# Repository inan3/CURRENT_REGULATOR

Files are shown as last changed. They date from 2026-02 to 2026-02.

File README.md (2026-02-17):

PCB Module based on STM32G491RET6 acting as a water sensor just for tests purposes. Nominal working voltage is 12V.
It is designed to receive commands either by UART or LIN-BUS containing info about:
  1. How many voltage between 0-3.3V to put in a connector A. 
     DAC_OUT1 from the STM32 is used for this purpose.
  2. How many current between 0-20mA to put in a connector B.
     DAC_OUT2 from the STM32 is used for this purpose. An equivalent voltage is generated from the DAC that will go through a phase of voltage-current conversion with the Improved Howland Current Pump achieving an outside current from 0mA to 20mA with 0V-3.3V.
  3. Toggle between 0V & 12V that must reach a connector C.
     This phase is achieved with high side switching topology to toggle 4 different pins of 2 separate connectores to toggle between 0V and 12V.

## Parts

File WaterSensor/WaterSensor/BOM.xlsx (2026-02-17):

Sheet: BOM
Reference | Manufacturer P/N | JLCPCB P/N | Value | Manufacturer
C1 | CC0603JRX7R9BB104 | C91183 | 100nF 50V X7R ±5% 0603 | YAGEO
C2, C3 | CC0603CRNPO9BN8R2 | C277519 | 50V 8.2pF NP0 0603 | YAGEO
C4 | CC0603JRX7R9BB224 | C519575 | 220nF 50V X7R ±5% 0603 | YAGEO
C5, C6, C7 | CC0603KRX5R5BB106 | C109455 | 10uF 6.3V X5R ±10% | YAGEO
C8, C18 | CC0603JRX7R9BB103 | C115056 | 10nF 50V X7R ±5% 0603 | YAGEO
C9, C17, C20 | CC0603KRX5R9BB105 | C128624 | 1uF 50V X5R ±10% 0603 | YAGEO
C10, C11, C12, C13, C14, C16, C19, C35 | CC0603JRX7R9BB104 | C91183 | 100nF 50V X7R ±5% 0603 | YAGEO
C15 | CC0603KRX5R8BB475 | C326580 | 25V 4.7uF X5R ±10% 0603 | YAGEO
C21 | CC0603JRNPO9BN102 | C106246 | 1nF 50V NP0 ±5% 0603 | YAGEO
C22, C23 | CC0603KRX5R8BB225 | C309478 | 2.2uF 25V X5R ±10% 0603 | YAGEO
C24, C25, C26, C27, C28, C29, C30, C31, C32, C33 | CC0603JRX7R9BB104 | C91183 | 100nF 50V X7R ±5% 0603 | YAGEO
C34 | CC0805KKX5R7BB106 | C89827 | 10uF 16V X5R ±10% 0805 Multilayer Ceramic Capacitors MLCC - SMD/SMT ROHS | YAGEO
D1 | 1N5819WS | C191023 | 1 Independent 1A 25A 40V 500uA@40V 600mV@1A SOD-323 Schottky Diodes ROHS | Guangdong Hottech
D2 | 1N5819WS | C191023 | 1 Independent 1A 25A 40V 500uA@40V 600mV@1A SOD-323 Schottky Diodes ROHS | Guangdong Hottech
D3 | 1N5819WS | C191023 | 1 Independent 1A 25A 40V 500uA@40V 600mV@1A SOD-323 Schottky Diodes ROHS | Guangdong Hottech
D4 | 1N5819WS | C191023 | 1 Independent 1A 25A 40V 500uA@40V 600mV@1A SOD-323 Schottky Diodes ROHS | Guangdong Hottech
D5 | XL-1608UYC-06 | C965802 | Yellow LED | XingLight
D6 | XL-1608UGC-04 | C965804 | Green LED | XingLight
D7 | XL-1608SURC-06 | C965799 | Red LED | XingLight
D8 | XL-1608UBC-04 | C965807 | Blue LED | XingLight
FB1, FB3 | BLM18EG101TN1D | C76893 | -55℃~+125℃ 1 100Ω@100MHz 2A 45mΩ ±25% 0603 Ferrite Beads ROHS | Murata Electronics
FB2 | BLM18AG601SH1D | C73225 | -55℃~+125℃ 1 380mΩ 500mA 600Ω@100MHz ±25% 0603 Ferrite Beads ROHS | Murata Electronics
J1 | 20021321-00014C1LF | C3319516 | -40℃~+105℃ 1.27mm 1.27mm 14P 2 4.5mm Phosphor bronze Square Hole Surface Mount,Vertical Tin SMD,P=1.27mm Female Headers ROHS | Amphenol ICC
J2, J3, J7, J8 | 1724480002 | C5188718 | -40℃~+105℃ 1 13A 2 2P 2x1P 4.2mm 4.2mm 600V Black Brass PA Right Angle Tin UL94V-2 Plugin Wire To Board Connector ROHS | Molex
J4 | 436500427 | C563850 | -40℃~+105℃ 1 18.65mm 1x5P 3mm 5 5.57mm 5P 600V 8.5A 9.9mm Black Brass Micro-Fit(MX 3.0) Pillar Through Hole Tin UL94V-0 Plugin,P=3mm Wire To Board Connector ROHS | Molex
J5 | 436500527 | C19183988 | -40℃~+105℃ 1 15.65mm 1x4P 3mm 4 4P 600V 8.5A Black Brass Through Hole Tin UL94V-0 Plugin,P=3mm Wire To Board Connector ROHS | Molex
J6 | 65100516121 | C5120592 | -40℃~+105℃ 1 1A 30V 5P Black Female Mini-B Surface Mount, Right Angle USB 2.0 SMD USB Connectors ROHS | Würth Elektronik
Q1, Q2, Q3, Q4, Q5, Q6, Q7, Q8 | BC848BLT1G | C163725 | -55℃~+150℃ 1 NPN 100MHz 100mA 110 225mW 250mV 30V 5V 5uA NPN SOT-23 Bipolar (BJT) ROHS | Onsemi
QM1, QM2, QM3, QM4, QM5, QM6, QM7, QM8 | SIS427EDN-T1-GE3 | C727478 | -55℃~+150℃ 1 P-Channel 1.2V 1.93nF 10.6mΩ@10V 15A 3.7W、52W 30V 66nC@10V PowerPAK1212-8 MOSFETs ROHS | Vishay Intertech
R1, R2, R3, R4, R5, R6, R7, R8 | CRT0603-BY-1003ELF | C4332041 | -55℃~+155℃ 100kΩ 100mW Thin Film Resistor ±0.1% ±25ppm/℃ 0603 Chip Resistor - Surface Mount ROHS | Bourns Inc.
R9, R10, R11 | RS-03K1001FT | C115325 | -55℃~+155℃ 100mW 1kΩ 50V Thick Film Resistor ±1% ±100ppm/℃ 0603 Chip Resistor - Surface Mount ROHS | FH (Guangdong Fenghua Advanced Tech)
R12 | RT0603BRE0750RL | C849792 | RES SMD 50 OHM 0.1% 1/10W 0603 | YAGEO
R13, R14, R15, R16 | EXB-28V220JX | C2649457 | 22Ω 4 63mW 8 ±200ppm/℃ ±5% 0402x4 Resistor Networks, Arrays ROHS | Panasonic Electronic Components
R17, R18, R19 | CR0603-FX-22R0ELF | C203424 | RES SMD 22 OHM 1% 1/10W 0603 | Bourns Inc.
R20 | CR0603-FX-1000ELF | C203215 | RES SMD 100 OHM 1% 1/10W 0603 | Bourns Inc.
R21, R22 | CR0603-FX-2200ELF | C203410 | RES SMD 220 OHM 1% 1/10W 0603 | Bourns Inc.
R23, R24 | CR0603-FX-1200ELF | C203262 | RES SMD 120 OHM 1% 1/10W 0603 | Bourns Inc.
R25, R26 | CR0603-FX-1002ELF | C840630 | RES SMD 10K OHM 1% 1/10W 0603 | Bourns Inc.
R27 | CRCW06031K50FKEAC | C844332 | RES 1.5K OHM 1% 1/10W 0603 | Vishay Dale
RSense1, RSense2 | RT0603BRD07165RL | C861151 | -55℃~+155℃ 100mW 165Ω 75V Thin Film Resistor ±0.1% ±25ppm/℃ 0603 Chip Resistor - Surface Mount ROHS | YAGEO
SW1 | TS04-66-43-BK-160-SMT | C4364498 | Switch | Same Sky (Formerly CUI Devices)
U1 | STM32G491RET6 | C3231005 | IC MCU 32BIT 512KB FLASH 64LQFP | STMicroelectronics
U2, U3, U8, U9, U14 | OPA2990IDR | C2058283 | IC OPAMP GP 2 CIRCUIT 8SOIC | Texas Instruments
U4 | LM1117MPX-3.3/NOPB | C9662 | IC REG LIN 3.3V 800MA SOT-223-4 | Texas Instruments
U5 | LM7805MPX/NOPB | C2848241 | IC REG LINEAR 5V 1.5A SOT-223-4 | Texas Instruments
U6 | TS5A23157QDGSRQ1 | C523778 | IC SWITCH SPDT X 2 15OHM 10VSSOP | Texas Instruments
U7 | TPD2E001DRLR | C150526 | TVS DIODE 5.5VWM SOT5 | Texas Instruments
U10 | CH340E | C99652 | USB/UART
U11 | MCP1501T-33E/CHY | C2156758 | IC VREF SERIES 3.3V SOT23-6 | Microchip Technology
U12 | TLIN1029DRQ1 | C190544 | Transceptor 1/1 LINbus 8-SOIC | Texas Instruments
U13 | SN74LV4051APWR | C7793 | IC MUX 8:1 75OHM 16TSSOP | Texas Instruments
U15 | OPA990IDBVR | C1855809 | -20V~-1.35V、1.35V~20V -40℃~+125℃ 1 1.1MHz 10pA 115dB 120uA 2.7V~40V 300uV 30nV/√Hz@1kHz 4.5V/us 40V 5pA 600nV/℃ 80mA Rail-to-Rail Input, Rail-to-Rail Output SOT-23-5 Operational Amplifier ROHS | Texas Instruments
XTAL1 | FA-128 24.0000MB-W | C2449805 | CRYSTAL 24.0000MHZ 12PF SMD | ECS

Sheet: Test
DigiKey P/N | Cantidad
OPA2990IDR | 5 | OPA2990IDR Texas Instruments | Integrated Circuits (ICs) | DigiKey (https://www.digikey.es/en/products/detail/texas-instruments/OPA2990IDR/10270185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) |  | ok
SN74LV4051APWR | 3 | SN74LV4051APWR Texas Instruments | Integrated Circuits (ICs) | DigiKey (https://www.digikey.es/en/products/detail/texas-instruments/SN74LV4051APWR/374749) |  | ok
BC848BLT1G | 5 | BC848BLT1G onsemi | Discrete Semiconductor Products | DigiKey (https://www.digikey.es/en/products/detail/onsemi/BC848BLT1G/918348) |  | ok
SIS427EDN-T1-GE3 | 5 | SIS427EDN-T1-GE3 Vishay Siliconix | Discrete Semiconductor Products | DigiKey (https://www.digikey.es/en/products/detail/vishay-siliconix/SIS427EDN-T1-GE3/4327726) |  | ok
TS5A23157QDGSRQ1 | 2 | TS5A23157QDGSRQ1 Texas Instruments | Integrated Circuits (ICs) | DigiKey (https://www.digikey.es/en/products/detail/texas-instruments/TS5A23157QDGSRQ1/3996775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) |  | ok
C321C103K3G5TA | 8 |  | 10nF | ok
K104K15X7RF5TL2 | 15 |  | 100nF | ok
MFP-25BRD52-100K | 16 |  | 100k | ok
MFR-25FRF52-165R | 8 |  | 165 | ok

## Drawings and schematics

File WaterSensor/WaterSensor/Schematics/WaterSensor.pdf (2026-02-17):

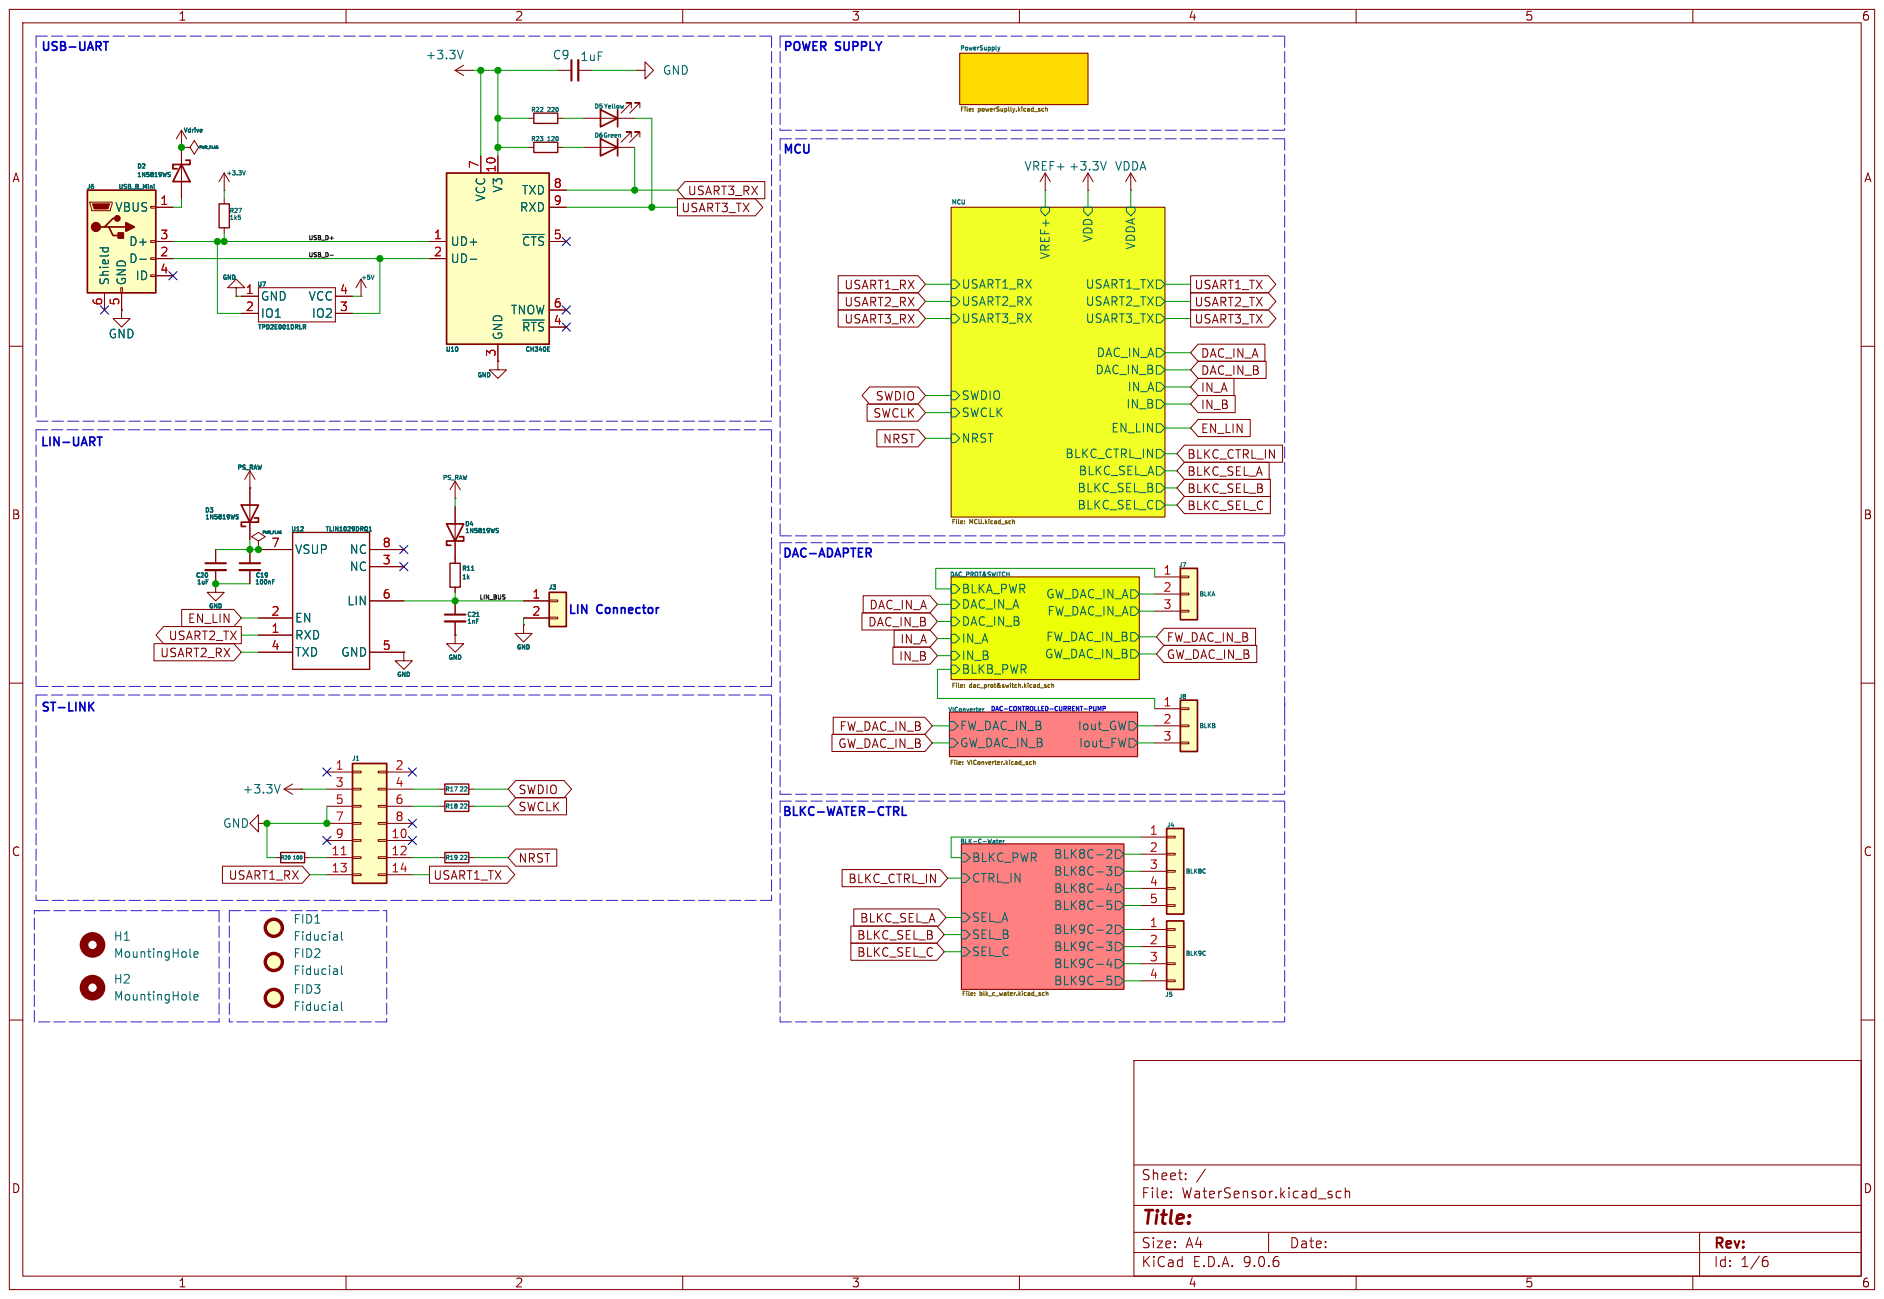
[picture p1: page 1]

Id: 1/6 Title: File: WaterSensor.kicad_sch Sheet: /

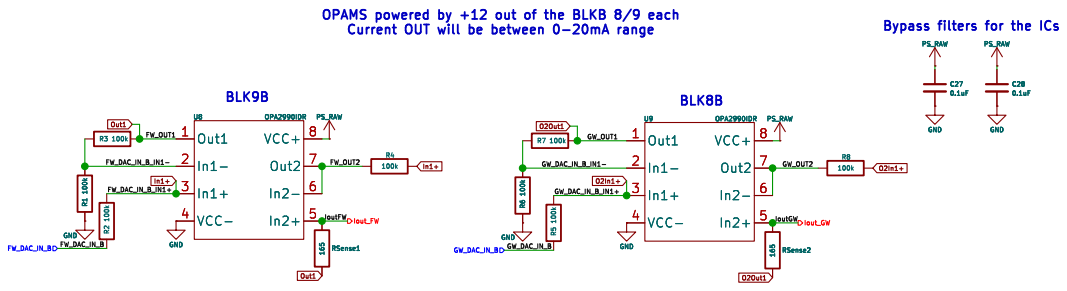
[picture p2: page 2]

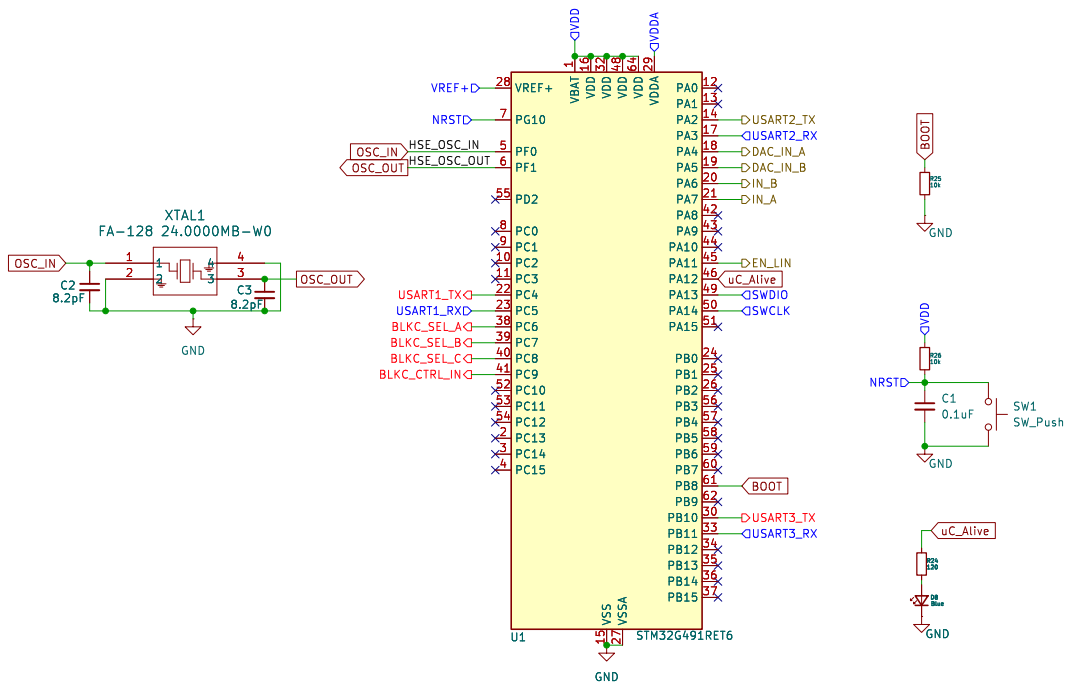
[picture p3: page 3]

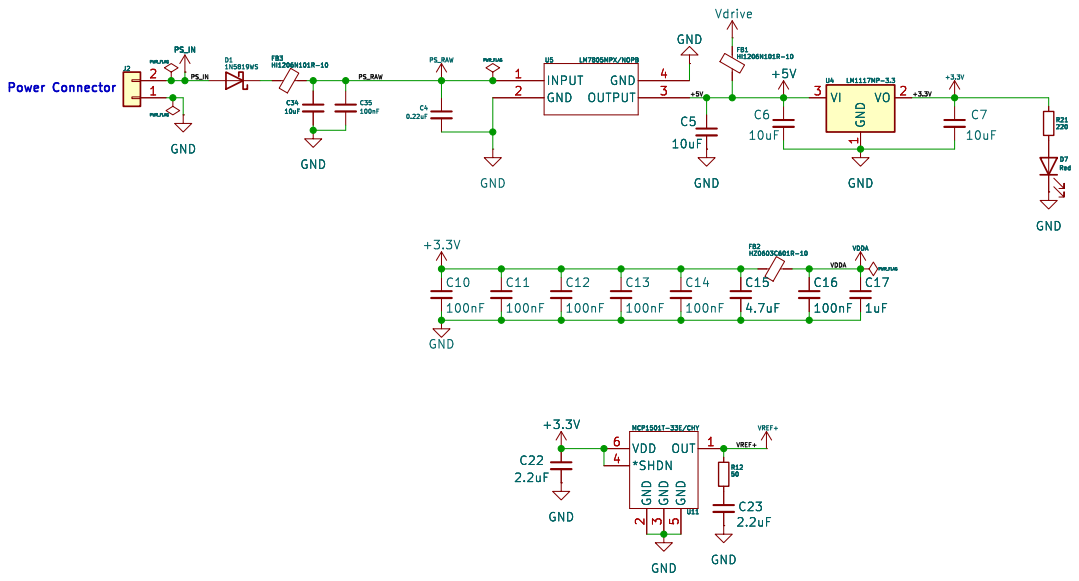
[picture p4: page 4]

Id: 4/6 Title: File: powerSuplly.kicad_sch Sheet: /PowerSupply/

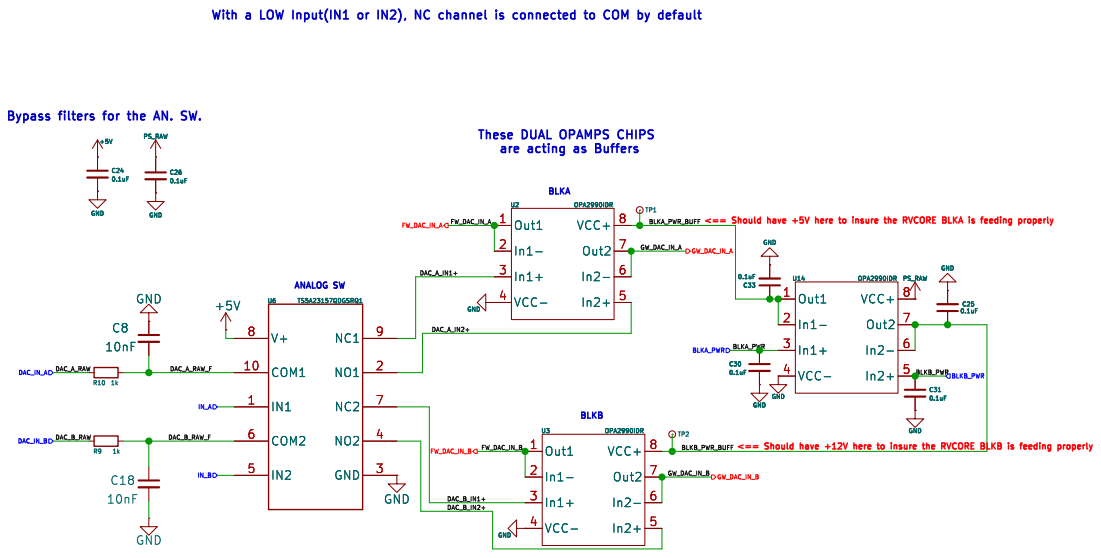
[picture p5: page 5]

Id: 5/6 Title: File: dac_prot&switch.kicad_sch Sheet: /DAC_PROT&SWITCH/

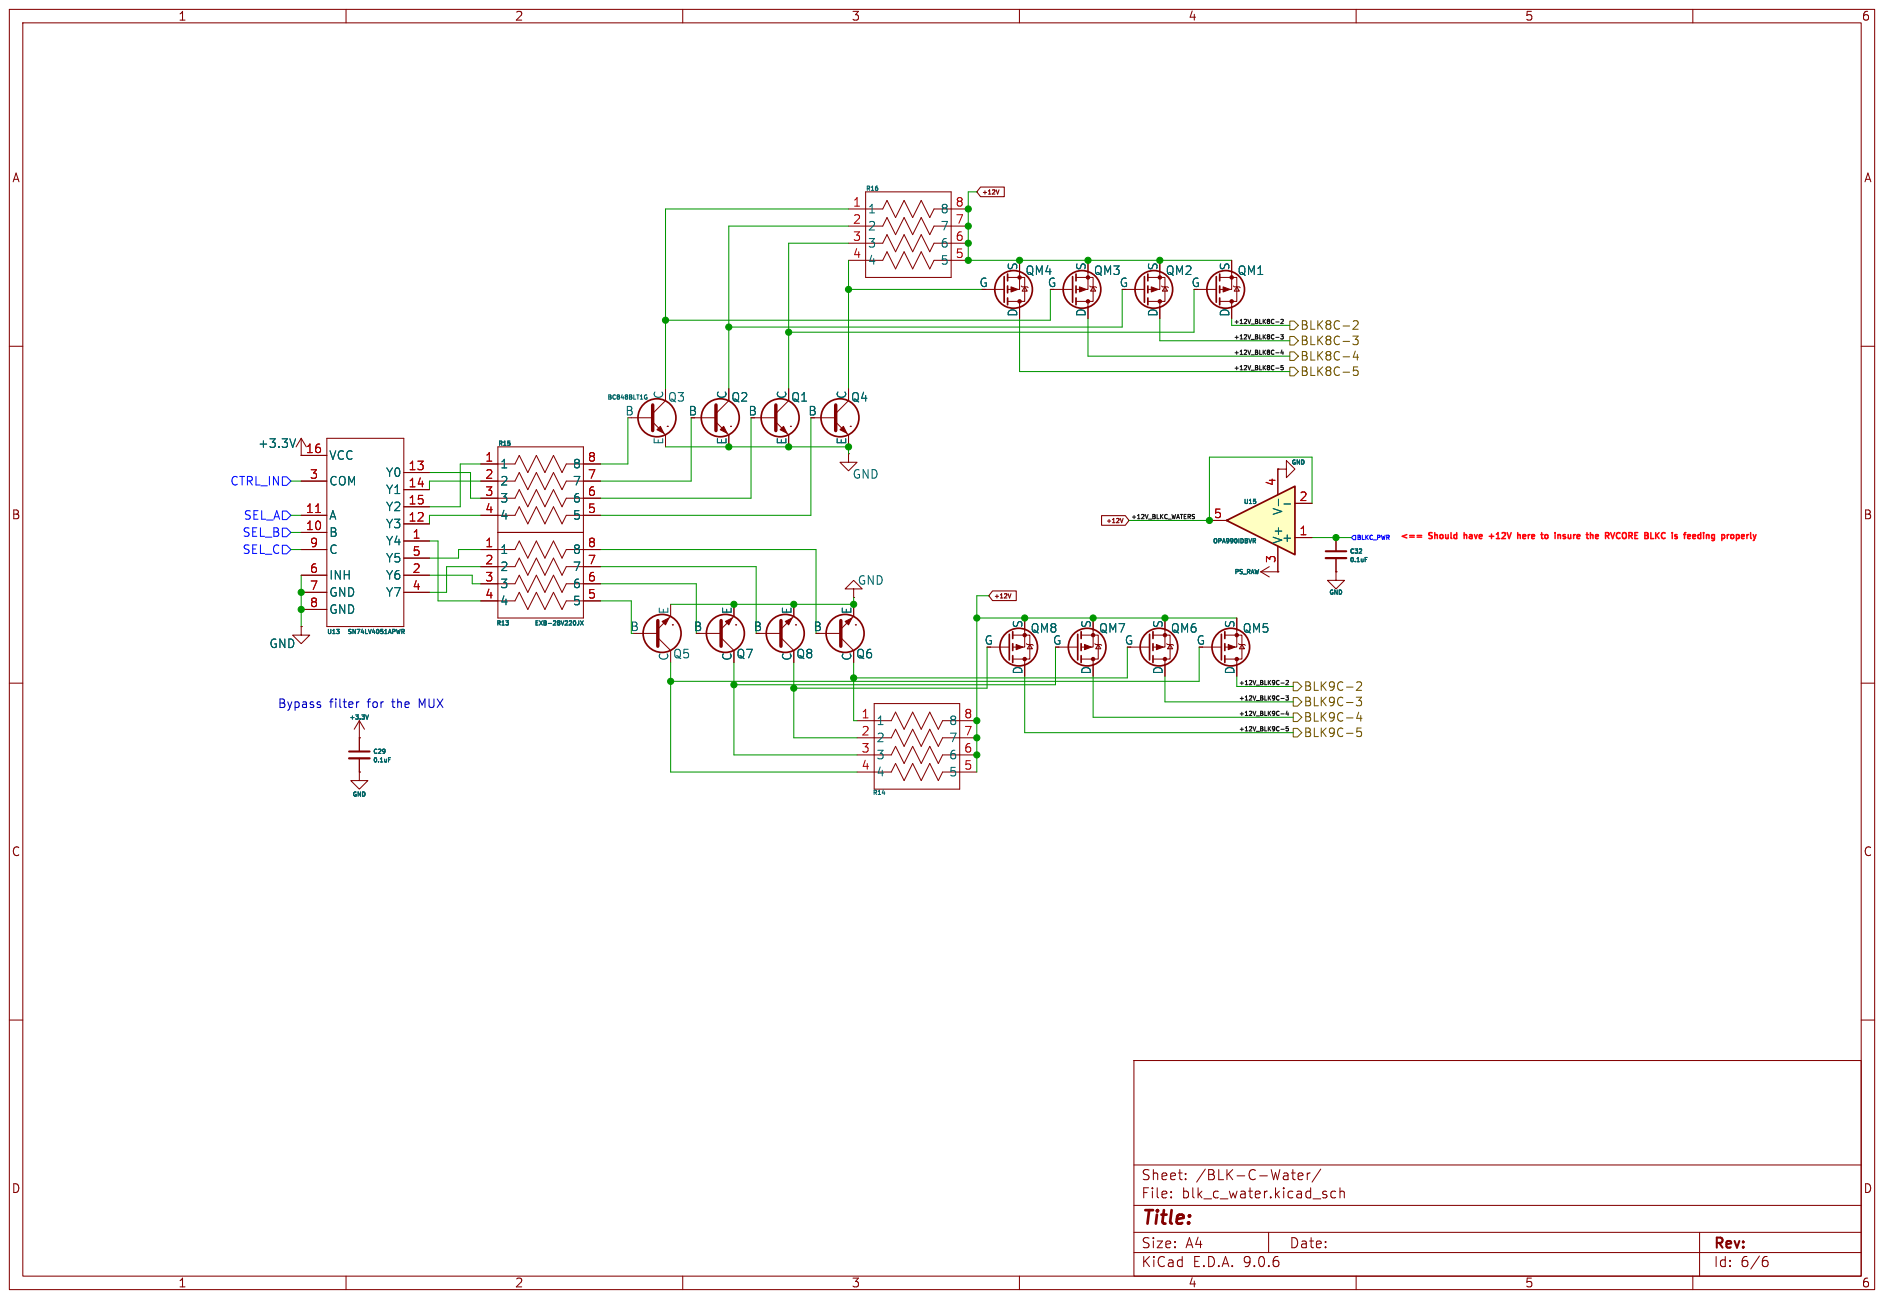
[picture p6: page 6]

+12V_BLK8C-2 +12V_BLK8C-4 +12V_BLK8C-5 Bypass filter for the MUX

Id: 6/6 Title: File: blk_c_water.kicad_sch Sheet: /BLK-C-Water/

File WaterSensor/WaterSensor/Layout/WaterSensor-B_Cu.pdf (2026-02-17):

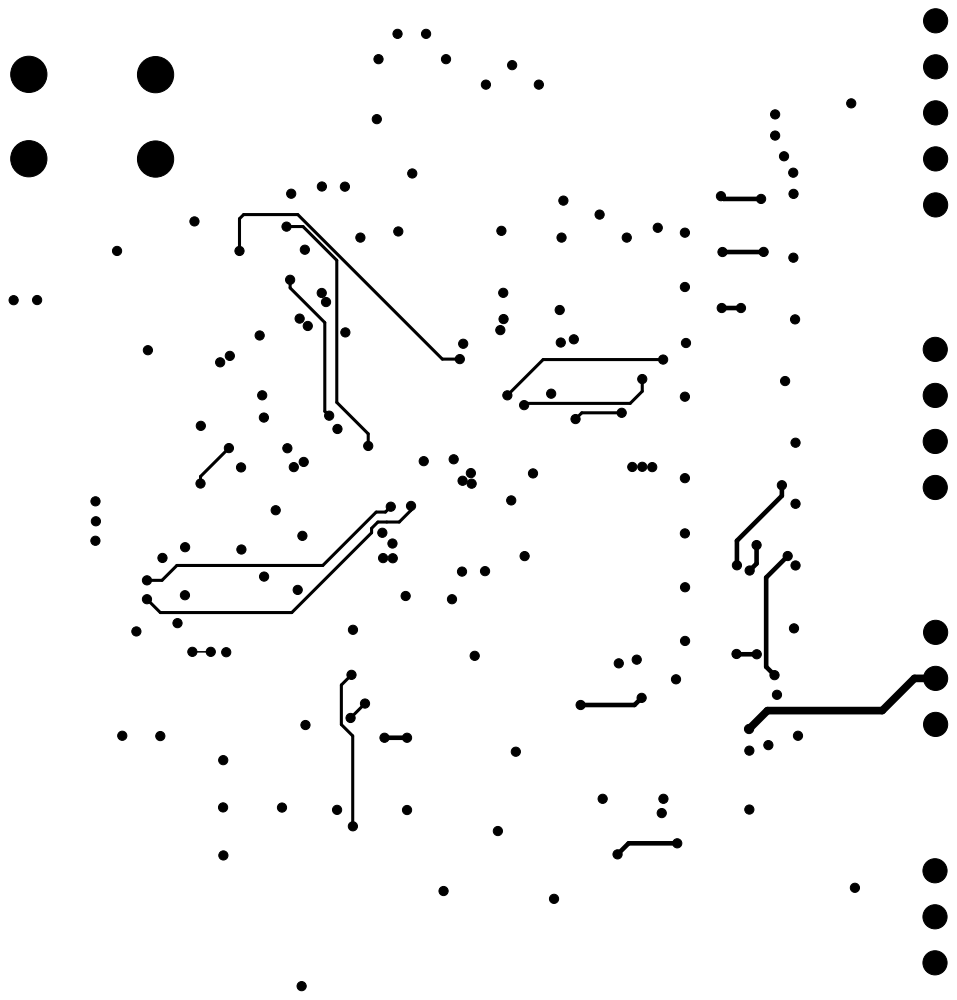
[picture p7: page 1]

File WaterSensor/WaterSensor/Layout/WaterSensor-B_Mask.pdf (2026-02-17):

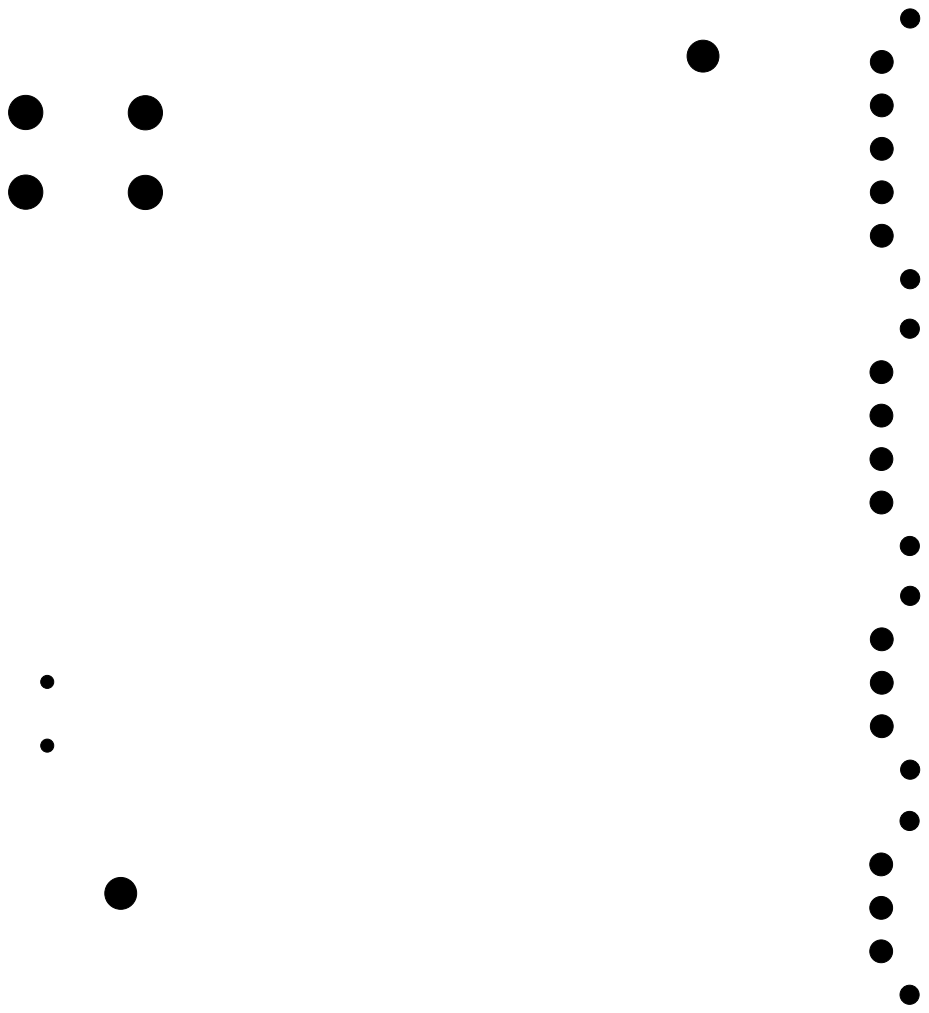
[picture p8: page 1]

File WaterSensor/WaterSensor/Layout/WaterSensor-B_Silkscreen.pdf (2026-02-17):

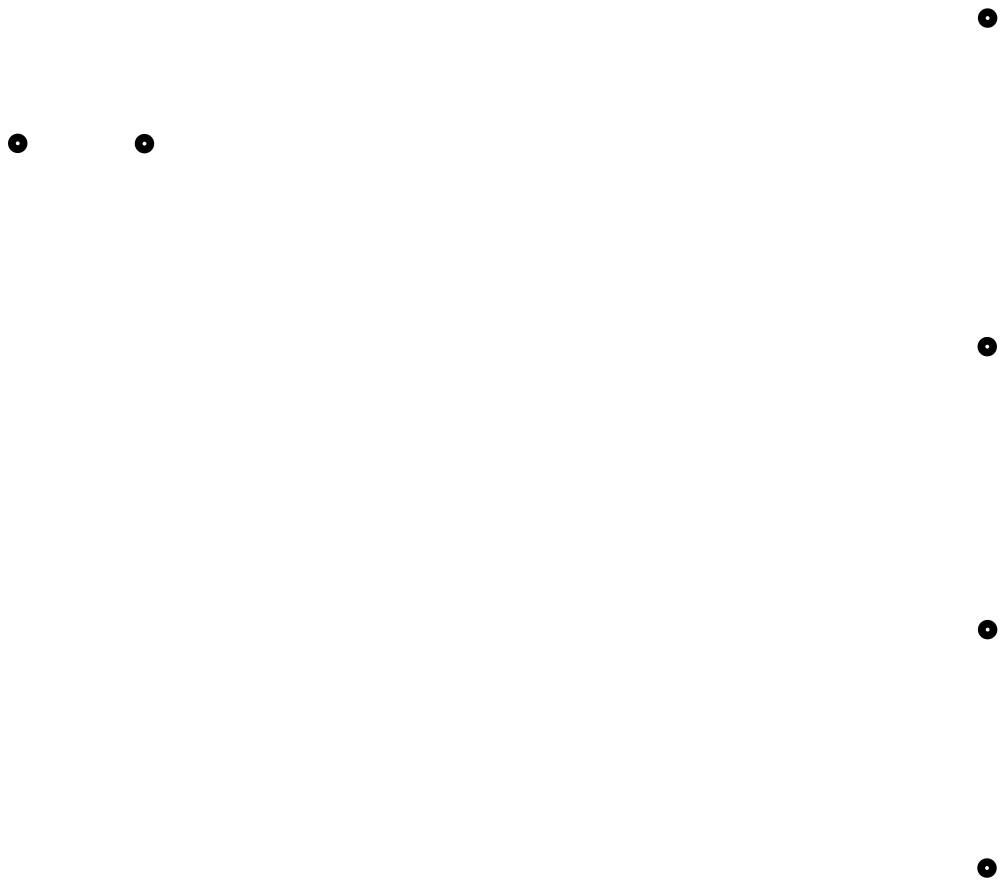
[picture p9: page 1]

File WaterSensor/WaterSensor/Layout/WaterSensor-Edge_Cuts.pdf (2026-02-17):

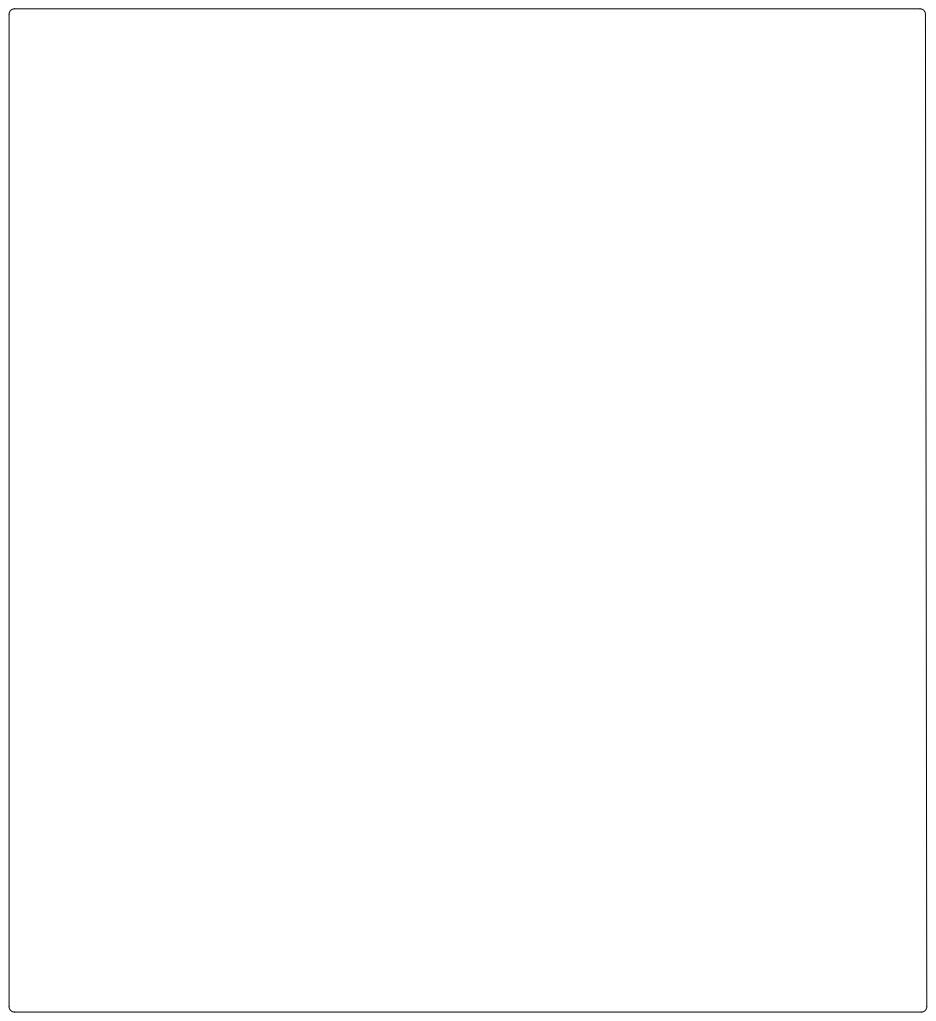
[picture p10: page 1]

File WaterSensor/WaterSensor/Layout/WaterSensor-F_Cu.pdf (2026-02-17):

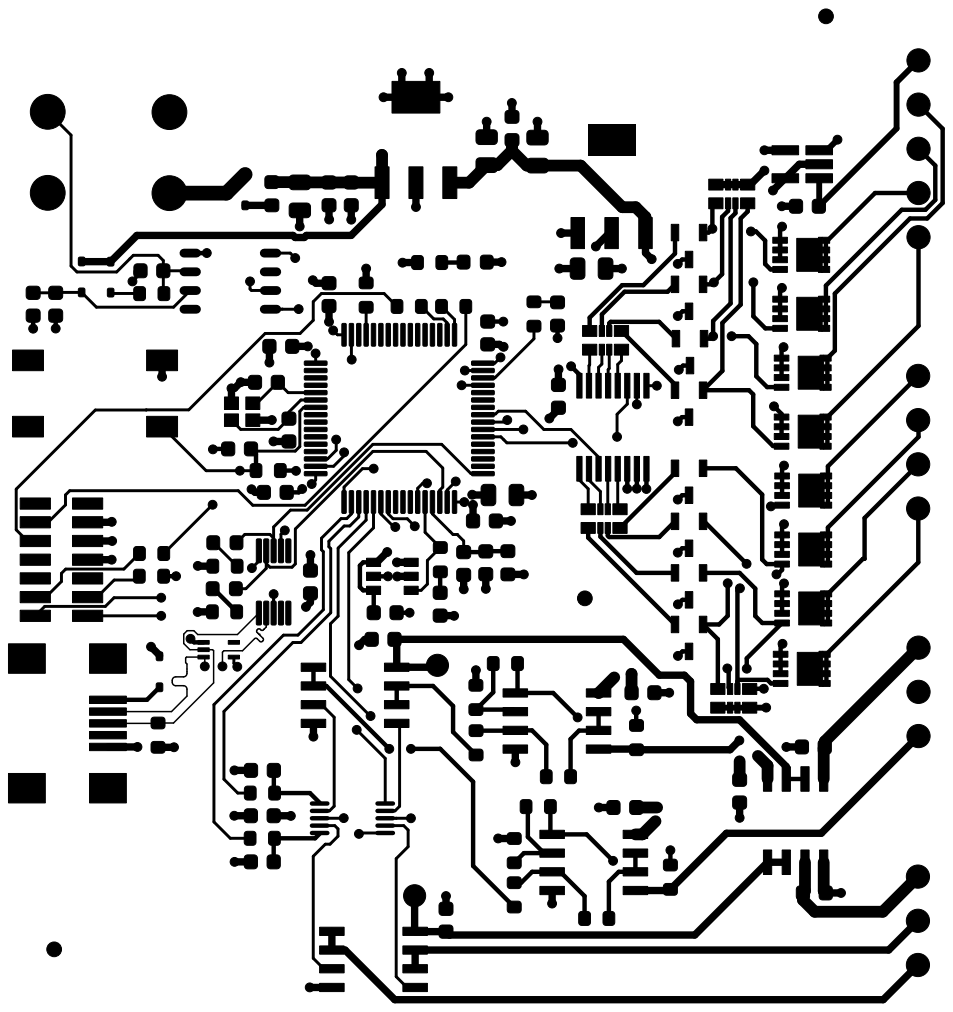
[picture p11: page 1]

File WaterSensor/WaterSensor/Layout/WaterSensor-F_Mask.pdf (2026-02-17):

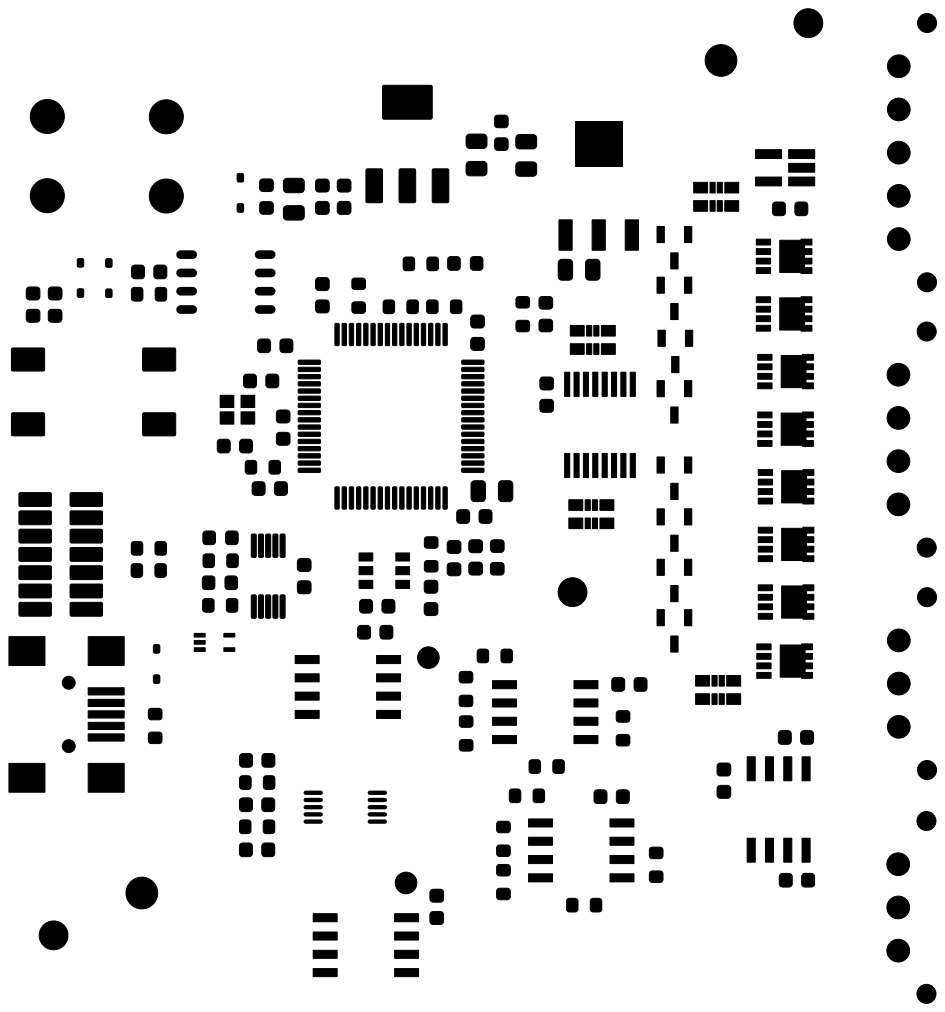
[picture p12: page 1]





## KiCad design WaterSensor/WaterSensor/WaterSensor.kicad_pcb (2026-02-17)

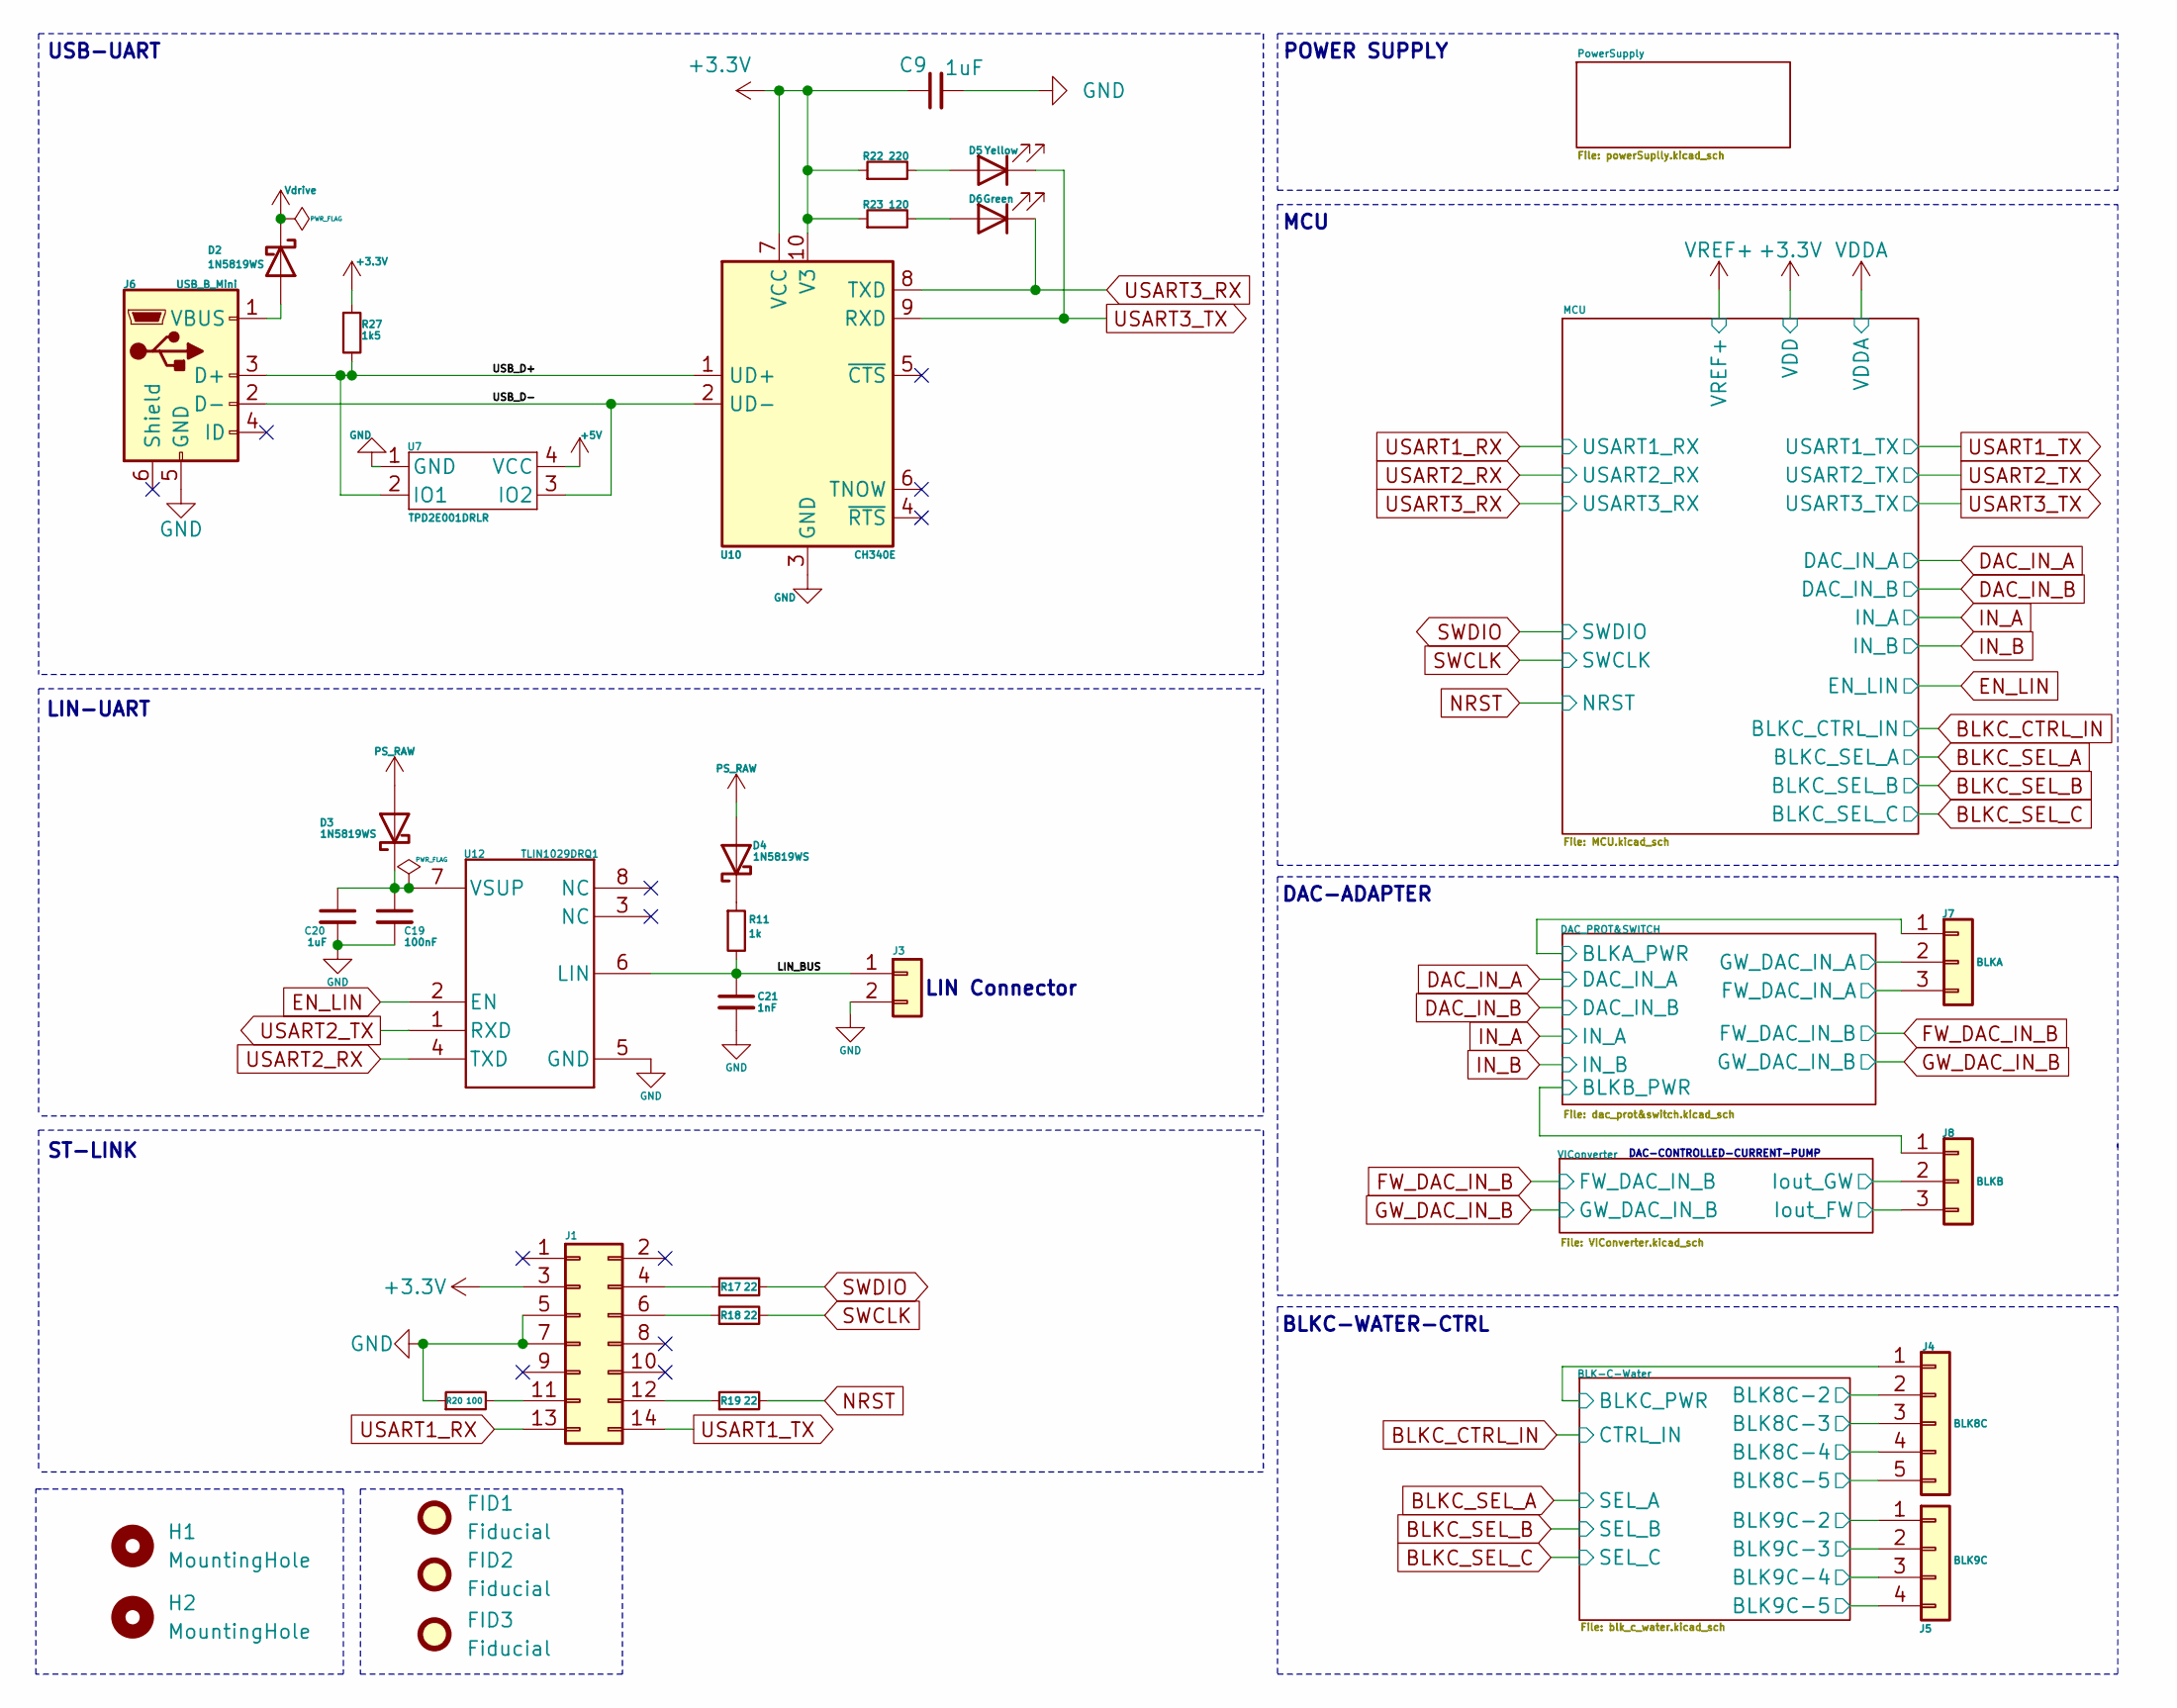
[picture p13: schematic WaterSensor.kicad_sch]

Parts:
C9, C20: 1uF; C_0603_1608Metric
C19: 100nF; C_0603_1608Metric
C21: 1nF; C_0603_1608Metric
D2, D3, D4: 1N5819WS; D_SOD-323
D5: Yellow; LED_0603_1608Metric
D6: Green; LED_0603_1608Metric
FID1, FID2, FID3: Fiducial; Fiducial_1mm_Mask2mm
H1, H2: MountingHole; MountingHole_2.2mm_M2
J1: ST-LINK; Connector_IDC_02x07_1_27mm_SMD
J3: LIN; Conn_1x2_MiniFit_1724480002
J4: BLK8C; Conn_1x5_MicroFit_436500527
J5: BLK9C; Conn_1x4_MicroFit_0436500427
J6: USB_B_Mini; USB_Mini-B_Wuerth_65100516121_Horizontal
J7: BLKA; Conn_1x3_MicroFit_436500327
J8: BLKB; Conn_1x3_MicroFit_436500327
R11: 1k; R_0603_1608Metric
R17, R18, R19: 22; R_0603_1608Metric
R20: 100; R_0603_1608Metric
R22: 220; R_0603_1608Metric
R23: 120; R_0603_1608Metric
R27: 1k5; R_0603_1608Metric
U7: TPD2E001DRLR; DRL5-M
U10: CH340E; MSOP-10_3x3mm_P0.5mm
U12: TLIN1029DRQ1; D0008A_N

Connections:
+3.3V: C9.1, J1.3, R22.1, R23.1, R27.1, U10.7 (VCC), U10.10 (V3); also elsewhere on the board
+5V: U7.4 (VCC); also elsewhere on the board
/BLK-C-Water/+12V_BLK8C-2: J4.2; also elsewhere on the board
/BLK-C-Water/+12V_BLK8C-3: J4.3; also elsewhere on the board
/BLK-C-Water/+12V_BLK8C-4: J4.4; also elsewhere on the board
/BLK-C-Water/+12V_BLK8C-5: J4.5; also elsewhere on the board
/BLK-C-Water/+12V_BLK9C-2: J5.1; also elsewhere on the board
/BLK-C-Water/+12V_BLK9C-3: J5.2; also elsewhere on the board
/BLK-C-Water/+12V_BLK9C-4: J5.3; also elsewhere on the board
/BLK-C-Water/+12V_BLK9C-5: J5.4; also elsewhere on the board
/BLK-C-Water/BLKC_PWR: J4.1; also elsewhere on the board
/DAC_PROT&SWITCH/BLKA_PWR: J7.1; also elsewhere on the board
/DAC_PROT&SWITCH/BLKB_PWR: J8.1; also elsewhere on the board
/DAC_PROT&SWITCH/FW_DAC_IN_A: J7.3; also elsewhere on the board
/DAC_PROT&SWITCH/GW_DAC_IN_A: J7.2; also elsewhere on the board
/LIN_BUS: C21.1, J3.1, R11.2, U12.6 (LIN)
/USB_D+: J6.3 (D+), R27.2, U7.2 (IO1), U10.1 (UD+)
/USB_D-: J6.2 (D-), U7.3 (IO2), U10.2 (UD-)
/VIConverter/IoutFW: J8.3; also elsewhere on the board
/VIConverter/IoutGW: J8.2; also elsewhere on the board
EN_LIN: U12.2 (EN); also elsewhere on the board
GND: C9.2, C19.2, C20.2, C21.2, J1.5, J1.7, J3.2, J6.5 (GND), R20.1, U7.1 (GND), U10.3 (GND), U12.5 (GND); also elsewhere on the board
NRST: R19.2; also elsewhere on the board
unnamed: D2.2 (A), J6.1 (VBUS)
unnamed: C19.1, C20.1, D3.1 (K), U12.7 (VSUP)
unnamed: D4.1 (K), R11.1
unnamed: D5.2 (A), R22.2
unnamed: D6.2 (A), R23.2
unnamed: J1.4, R17.1
unnamed: J1.6, R18.1
unnamed: J1.11, R20.2
unnamed: J1.12, R19.1
PS_RAW: D3.2 (A), D4.2 (A); also elsewhere on the board
SWCLK: R18.2; also elsewhere on the board
SWDIO: R17.2; also elsewhere on the board
USART1_RX: J1.13; also elsewhere on the board
USART1_TX: J1.14; also elsewhere on the board
USART2_RX: U12.4 (TXD); also elsewhere on the board
USART2_TX: U12.1 (RXD); also elsewhere on the board
USART3_RX: D6.1 (K), U10.8 (TXD); also elsewhere on the board
USART3_TX: D5.1 (K), U10.9 (RXD); also elsewhere on the board
Vdrive: D2.1 (K); also elsewhere on the board

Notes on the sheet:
LIN Connector
DAC-CONTROLLED-CURRENT-PUMP
DAC-ADAPTER
ST-LINK
MCU
LIN-UART
POWER SUPPLY
BLKC-WATER-CTRL
USB-UART

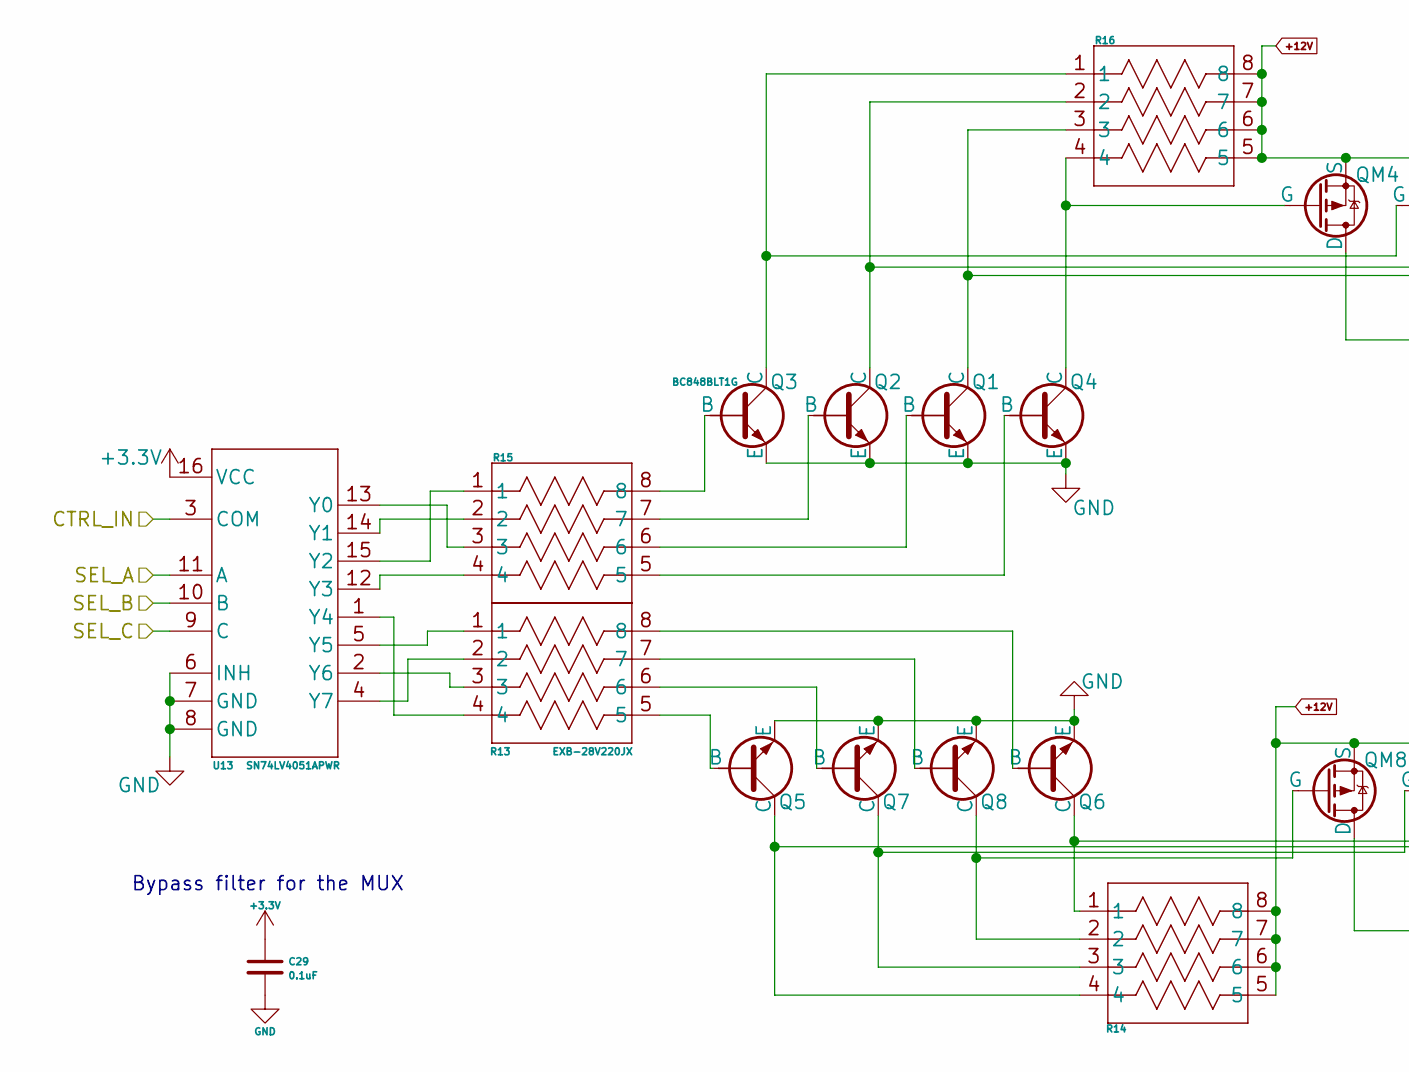
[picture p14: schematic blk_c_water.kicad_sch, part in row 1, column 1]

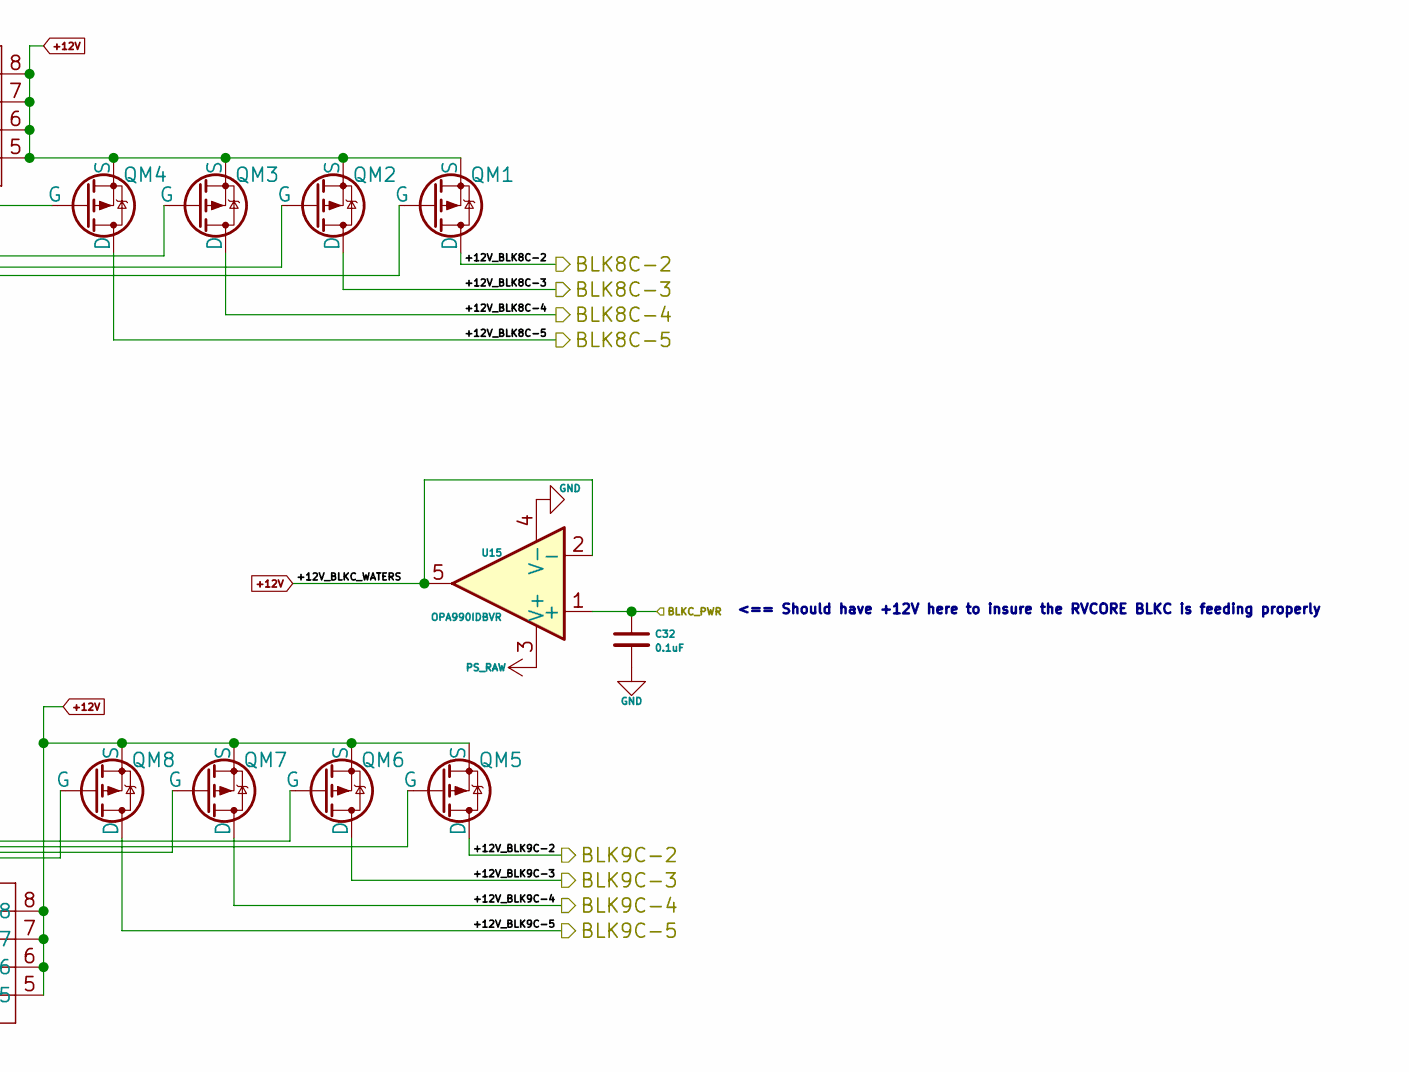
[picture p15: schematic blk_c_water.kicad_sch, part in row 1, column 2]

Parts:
C29, C32: 0.1uF; C_0603_1608Metric
Q1, Q2, Q3, Q4, Q5, Q6, Q7, Q8: BC848BLT1G; SOT-23_ONS-L
QM1, QM2, QM3, QM4, QM5, QM6, QM7, QM8: PMOS; LIB-SIS862DNT1GE3
R13, R14, R15, R16: EXB-28V220JX; EXB28V_PAN
U13: SN74LV4051APWR; PW16
U15: OPA990IDBVR; DBV0005A-IPC_A

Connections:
+3.3V: C29.1, U13.16 (VCC); also elsewhere on the board
+12V: QM1.3 (S), QM2.3 (S), QM3.3 (S), QM4.3 (S), QM5.3 (S), QM6.3 (S), QM7.3 (S), QM8.3 (S), R14.5, R14.6, R14.7, R14.8, R16.5, R16.6, R16.7, R16.8, U15.2 (-), U15.5
/BLK-C-Water/+12V_BLK8C-2: QM1.1 (D); also elsewhere on the board
/BLK-C-Water/+12V_BLK8C-3: QM2.1 (D); also elsewhere on the board
/BLK-C-Water/+12V_BLK8C-4: QM3.1 (D); also elsewhere on the board
/BLK-C-Water/+12V_BLK8C-5: QM4.1 (D); also elsewhere on the board
/BLK-C-Water/+12V_BLK9C-2: QM5.1 (D); also elsewhere on the board
/BLK-C-Water/+12V_BLK9C-3: QM6.1 (D); also elsewhere on the board
/BLK-C-Water/+12V_BLK9C-4: QM7.1 (D); also elsewhere on the board
/BLK-C-Water/+12V_BLK9C-5: QM8.1 (D); also elsewhere on the board
/BLK-C-Water/BLKC_PWR: C32.1, U15.1 (+); also elsewhere on the board
BLKC_CTRL_IN: U13.3 (COM); also elsewhere on the board
BLKC_SEL_A: U13.11 (A); also elsewhere on the board
BLKC_SEL_B: U13.10 (B); also elsewhere on the board
BLKC_SEL_C: U13.9 (C); also elsewhere on the board
GND: C29.2, C32.2, Q1.3 (E), Q2.3 (E), Q3.3 (E), Q4.3 (E), Q5.3 (E), Q6.3 (E), Q7.3 (E), Q8.3 (E), U13.6 (INH), U13.7 (GND), U13.8 (GND), U15.4 (V-); also elsewhere on the board
unnamed: Q1.2 (B), R15.6
unnamed: Q1.1 (C), QM1.2 (G), R16.3
unnamed: Q2.2 (B), R15.7
unnamed: Q2.1 (C), QM2.2 (G), R16.2
unnamed: Q3.2 (B), R15.8
unnamed: Q3.1 (C), QM3.2 (G), R16.1
unnamed: Q4.2 (B), R15.5
unnamed: Q4.1 (C), QM4.2 (G), R16.4
unnamed: Q5.2 (B), R13.5
unnamed: Q5.1 (C), QM5.2 (G), R14.4
unnamed: Q6.2 (B), R13.8
unnamed: Q6.1 (C), QM6.2 (G), R14.1
unnamed: Q7.2 (B), R13.6
unnamed: Q7.1 (C), QM7.2 (G), R14.3
unnamed: Q8.2 (B), R13.7
unnamed: Q8.1 (C), QM8.2 (G), R14.2
unnamed: R15.3, U13.13 (Y0)
unnamed: R15.2, U13.14 (Y1)
unnamed: R15.1, U13.15 (Y2)
unnamed: R15.4, U13.12 (Y3)
unnamed: R13.4, U13.1 (Y4)
unnamed: R13.1, U13.5 (Y5)
unnamed: R13.3, U13.2 (Y6)
unnamed: R13.2, U13.4 (Y7)
PS_RAW: U15.3 (V+); also elsewhere on the board

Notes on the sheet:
<== Should have +12V here to insure the RVCORE BLKC is feeding properly
Bypass filter for the MUX

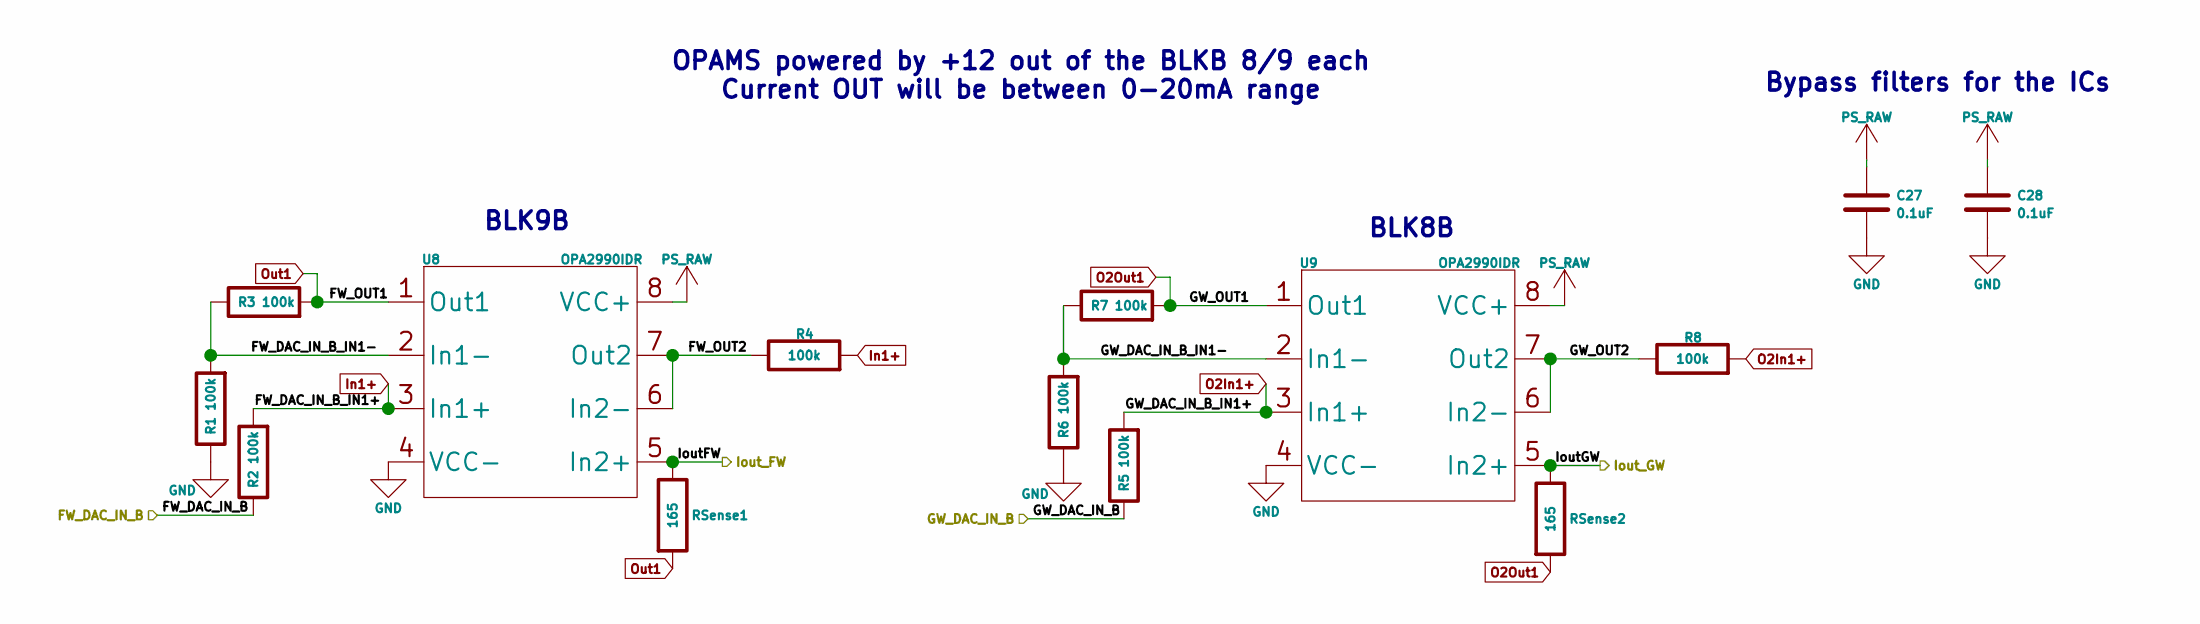
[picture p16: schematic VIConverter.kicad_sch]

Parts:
C27, C28: 0.1uF; C_0603_1608Metric
R1, R2, R3, R4, R5, R6, R7, R8: 100k; R_0603_1608Metric
RSense1, RSense2: 165; R_0603_1608Metric
U8, U9: OPA2990IDR; D8_TEX-M

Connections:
/VIConverter/FW_DAC_IN_B_IN1-: R1.2, R3.1, U8.2 (In1-)
/VIConverter/FW_OUT2: R4.1, U8.6 (In2-), U8.7 (Out2)
/VIConverter/GW_DAC_IN_B_IN1-: R6.2, R7.1, U9.2 (In1-)
/VIConverter/GW_OUT2: R8.1, U9.6 (In2-), U9.7 (Out2)
/VIConverter/IoutFW: RSense1.1, U8.5 (In2+); also elsewhere on the board
/VIConverter/IoutGW: RSense2.1, U9.5 (In2+); also elsewhere on the board
FW_DAC_IN_B: R2.1; also elsewhere on the board
GND: C27.2, C28.2, R1.1, R6.1, U8.4 (VCC-), U9.4 (VCC-); also elsewhere on the board
GW_DAC_IN_B: R5.1; also elsewhere on the board
In1+: R2.2, R4.2, U8.3 (In1+)
O2In1+: R5.2, R8.2, U9.3 (In1+)
O2Out1: R7.2, RSense2.2, U9.1 (Out1)
Out1: R3.2, RSense1.2, U8.1 (Out1)
PS_RAW: C27.1, C28.1, U8.8 (VCC+), U9.8 (VCC+); also elsewhere on the board

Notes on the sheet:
BLK8B
BLK9B
Bypass filters for the ICs
OPAMS powered by +12 out of the BLKB 8/9 each Current OUT will be between 0-20mA range

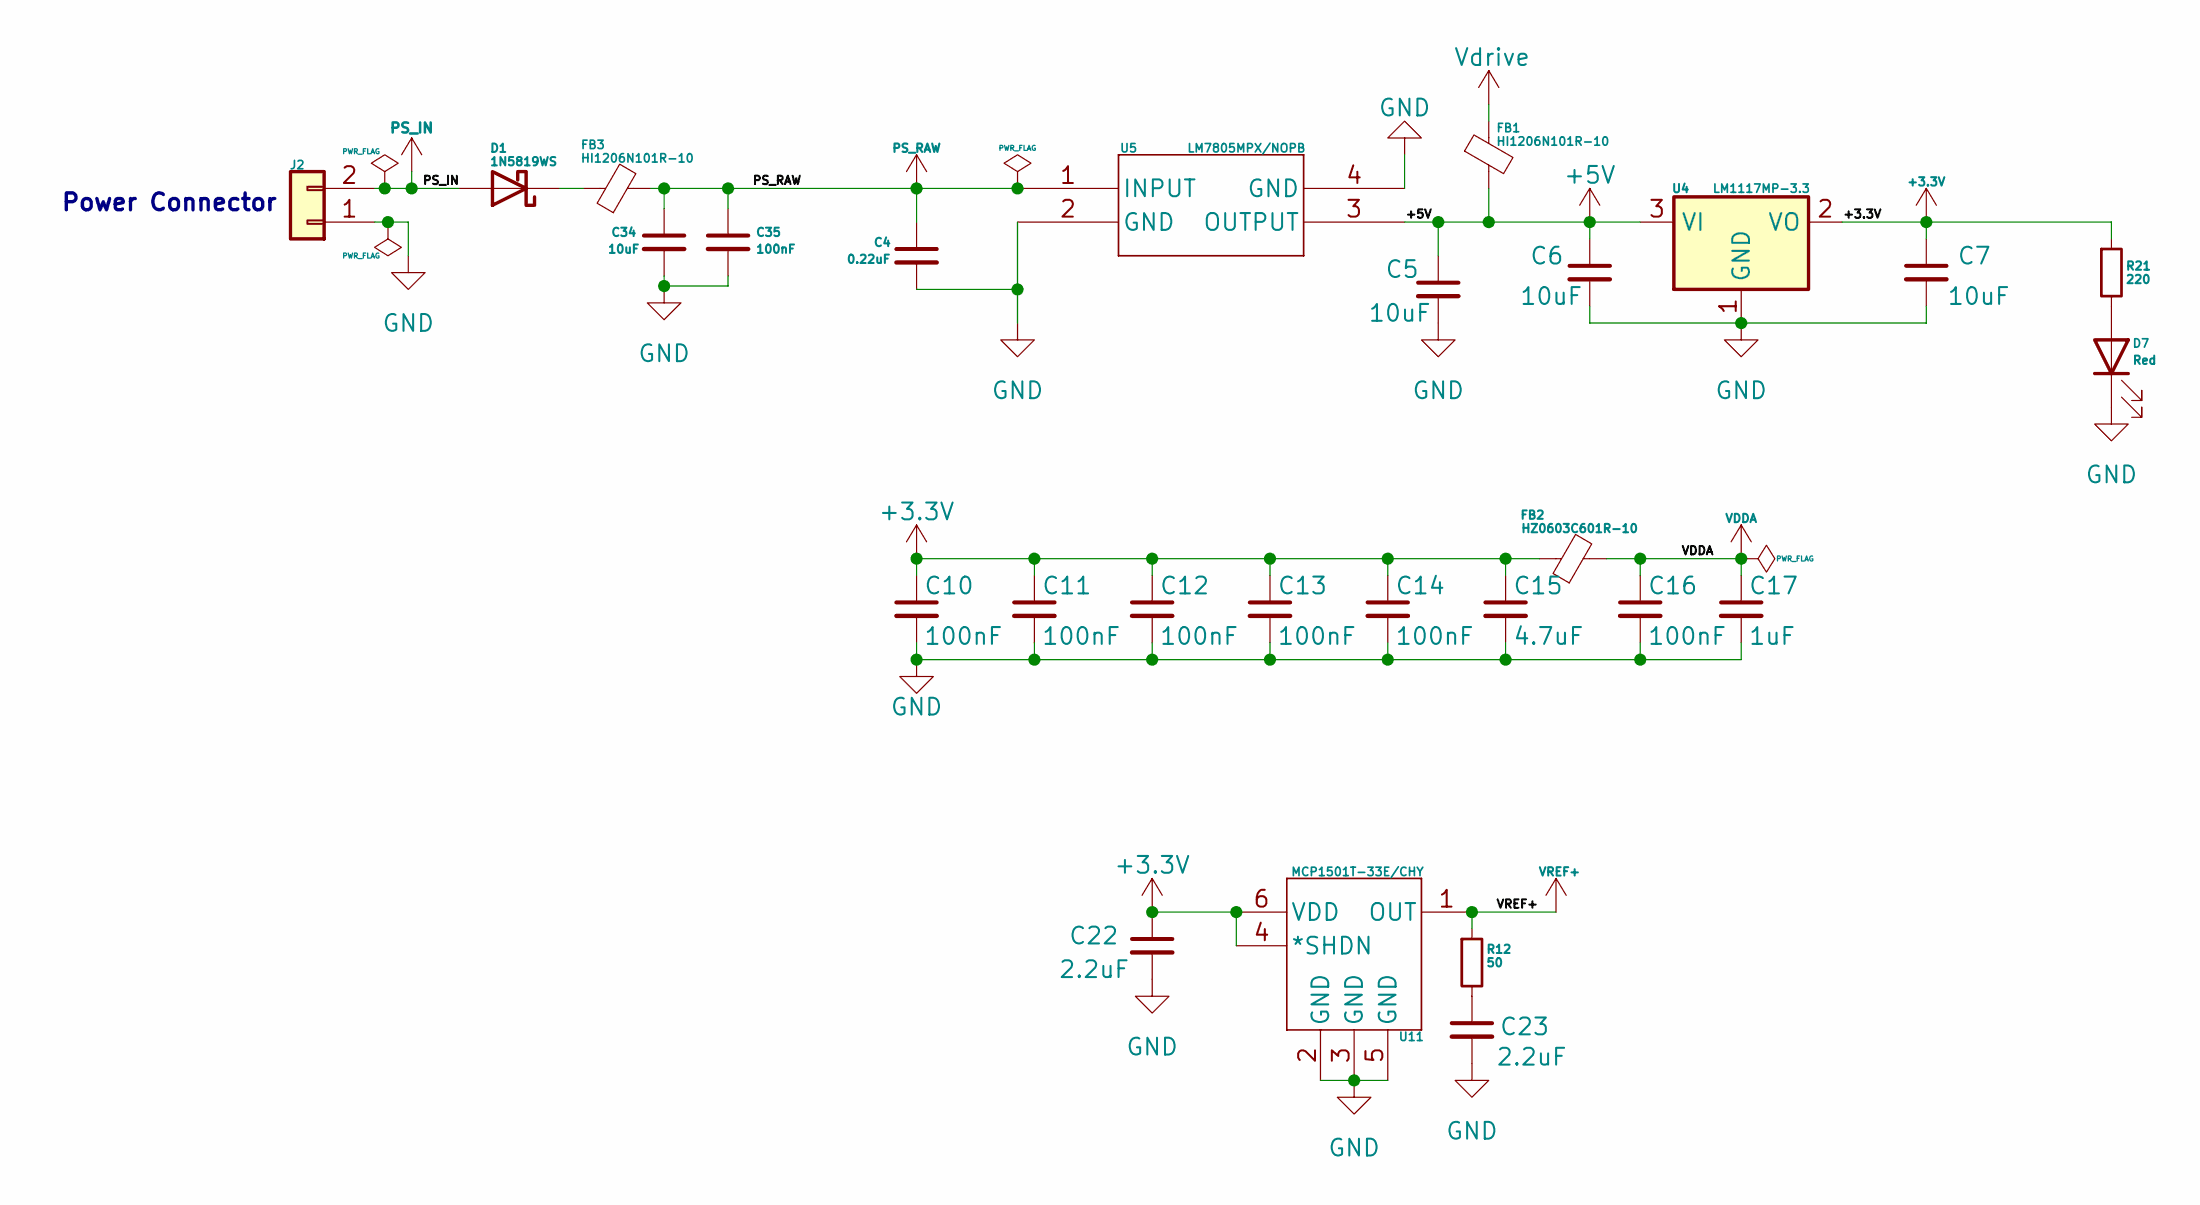
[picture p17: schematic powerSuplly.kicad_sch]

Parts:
C4: 0.22uF; C_0603_1608Metric
C5, C6, C7, C34: 10uF; C_0805_2012Metric
C10, C11, C12, C13, C14, C16, C35: 100nF; C_0603_1608Metric
C15: 4.7uF; C_0805_2012Metric
C17: 1uF; C_0603_1608Metric
C22, C23: 2.2uF; C_0603_1608Metric
D1: 1N5819WS; D_SOD-323
D7: Red; LED_0603_1608Metric
FB1, FB3: HI1206N101R-10; L_0603_1608Metric
FB2: HZ0603C601R-10; L_0603_1608Metric
J2: PS_IN; Conn_1x2_MiniFit_1724480002
R12: 50; R_0603_1608Metric
R21: 220; R_0603_1608Metric
U4: LM1117MP-3.3; SOT223-318H_OSI-M
U5: LM7805MPX/NOPB; LM7805MPX_NOPB
U11: MCP1501T-33E/CHY; SOT-23-6_CHY_MCH

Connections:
+3.3V: C7.1, C10.1, C11.1, C12.1, C13.1, C14.1, C15.1, C22.1, FB2.1, R21.1, U4.2 (VO), U11.4 (*SHDN), U11.6 (VDD); also elsewhere on the board
+5V: C5.1, C6.1, FB1.2, U4.3 (VI), U5.3 (OUTPUT); also elsewhere on the board
GND: C4.2, C5.2, C6.2, C7.2, C10.2, C11.2, C12.2, C13.2, C14.2, C15.2, C16.2, C17.2, C22.2, C23.2, C34.2, C35.2, D7.1 (K), J2.1, U4.1 (GND), U5.2 (GND), U5.4 (GND), U11.2 (GND), U11.3 (GND), U11.5 (GND); also elsewhere on the board
unnamed: C23.1, R12.2
unnamed: D1.1 (K), FB3.1
unnamed: D7.2 (A), R21.2
PS_IN: D1.2 (A), J2.2
PS_RAW: C4.1, C34.1, C35.1, FB3.2, U5.1 (INPUT); also elsewhere on the board
VDDA: C16.1, C17.1, FB2.2; also elsewhere on the board
VREF+: R12.1, U11.1 (OUT); also elsewhere on the board
Vdrive: FB1.1; also elsewhere on the board

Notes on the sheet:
Power Connector

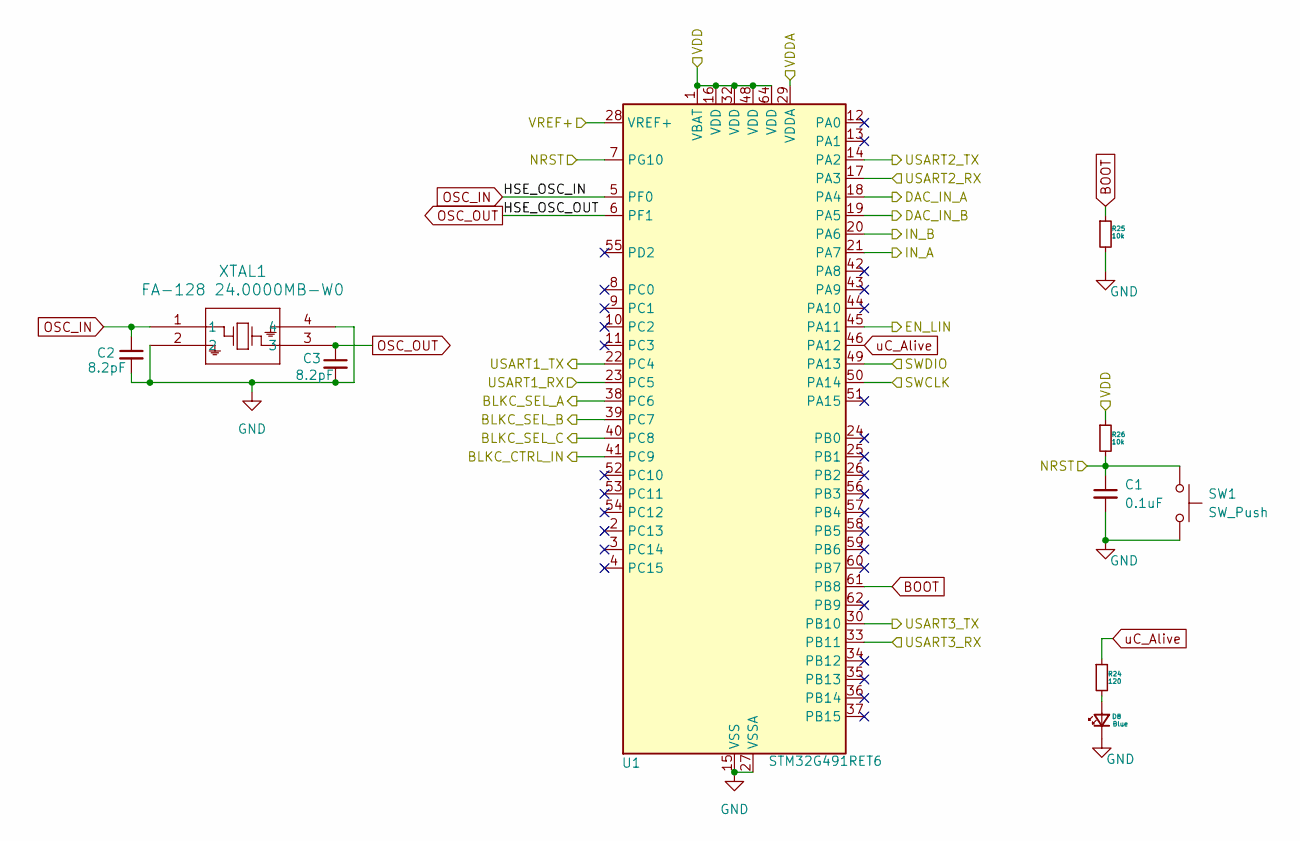
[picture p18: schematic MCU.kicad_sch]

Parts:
C1: 0.1uF; C_0603_1608Metric
C2, C3: 8.2pF; C_0603_1608Metric
D8: Blue; LED_0603_1608Metric
R24: 120; R_0603_1608Metric
R25, R26: 10k; R_0603_1608Metric
SW1: SW_Push; SW_TS04-66-43-BK-160-SMT
U1: STM32G491RET6; LQFP-64_10x10mm_P0.5mm
XTAL1: FA-128 24.0000MB-W0; FA-128_2x1p6_SEC

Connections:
+3.3V: R26.1, U1.1 (VBAT), U1.16 (VDD), U1.32 (VDD), U1.48 (VDD), U1.64 (VDD); also elsewhere on the board
BLKC_CTRL_IN: U1.41 (PC9); also elsewhere on the board
BLKC_SEL_A: U1.38 (PC6); also elsewhere on the board
BLKC_SEL_B: U1.39 (PC7); also elsewhere on the board
BLKC_SEL_C: U1.40 (PC8); also elsewhere on the board
BOOT: R25.1, U1.61 (PB8)
DAC_IN_A: U1.18 (PA4); also elsewhere on the board
DAC_IN_B: U1.19 (PA5); also elsewhere on the board
EN_LIN: U1.45 (PA11); also elsewhere on the board
GND: C1.2, C2.2, C3.2, D8.1 (K), R25.2, SW1.2, U1.15 (VSS), U1.27 (VSSA), U1.31 (VSS), U1.47 (VSS), U1.63 (VSS), XTAL1.2, XTAL1.4; also elsewhere on the board
IN_A: U1.21 (PA7); also elsewhere on the board
IN_B: U1.20 (PA6); also elsewhere on the board
NRST: C1.1, R26.2, SW1.1, U1.7 (PG10); also elsewhere on the board
unnamed: D8.2 (A), R24.2
OSC_IN: C2.1, U1.5 (PF0), XTAL1.1
OSC_OUT: C3.1, U1.6 (PF1), XTAL1.3
SWCLK: U1.50 (PA14); also elsewhere on the board
SWDIO: U1.49 (PA13); also elsewhere on the board
USART1_RX: U1.23 (PC5); also elsewhere on the board
USART1_TX: U1.22 (PC4); also elsewhere on the board
USART2_RX: U1.17 (PA3); also elsewhere on the board
USART2_TX: U1.14 (PA2); also elsewhere on the board
USART3_RX: U1.33 (PB11); also elsewhere on the board
USART3_TX: U1.30 (PB10); also elsewhere on the board
VDDA: U1.29 (VDDA); also elsewhere on the board
VREF+: U1.28 (VREF+); also elsewhere on the board
uC_Alive: R24.1, U1.46 (PA12)

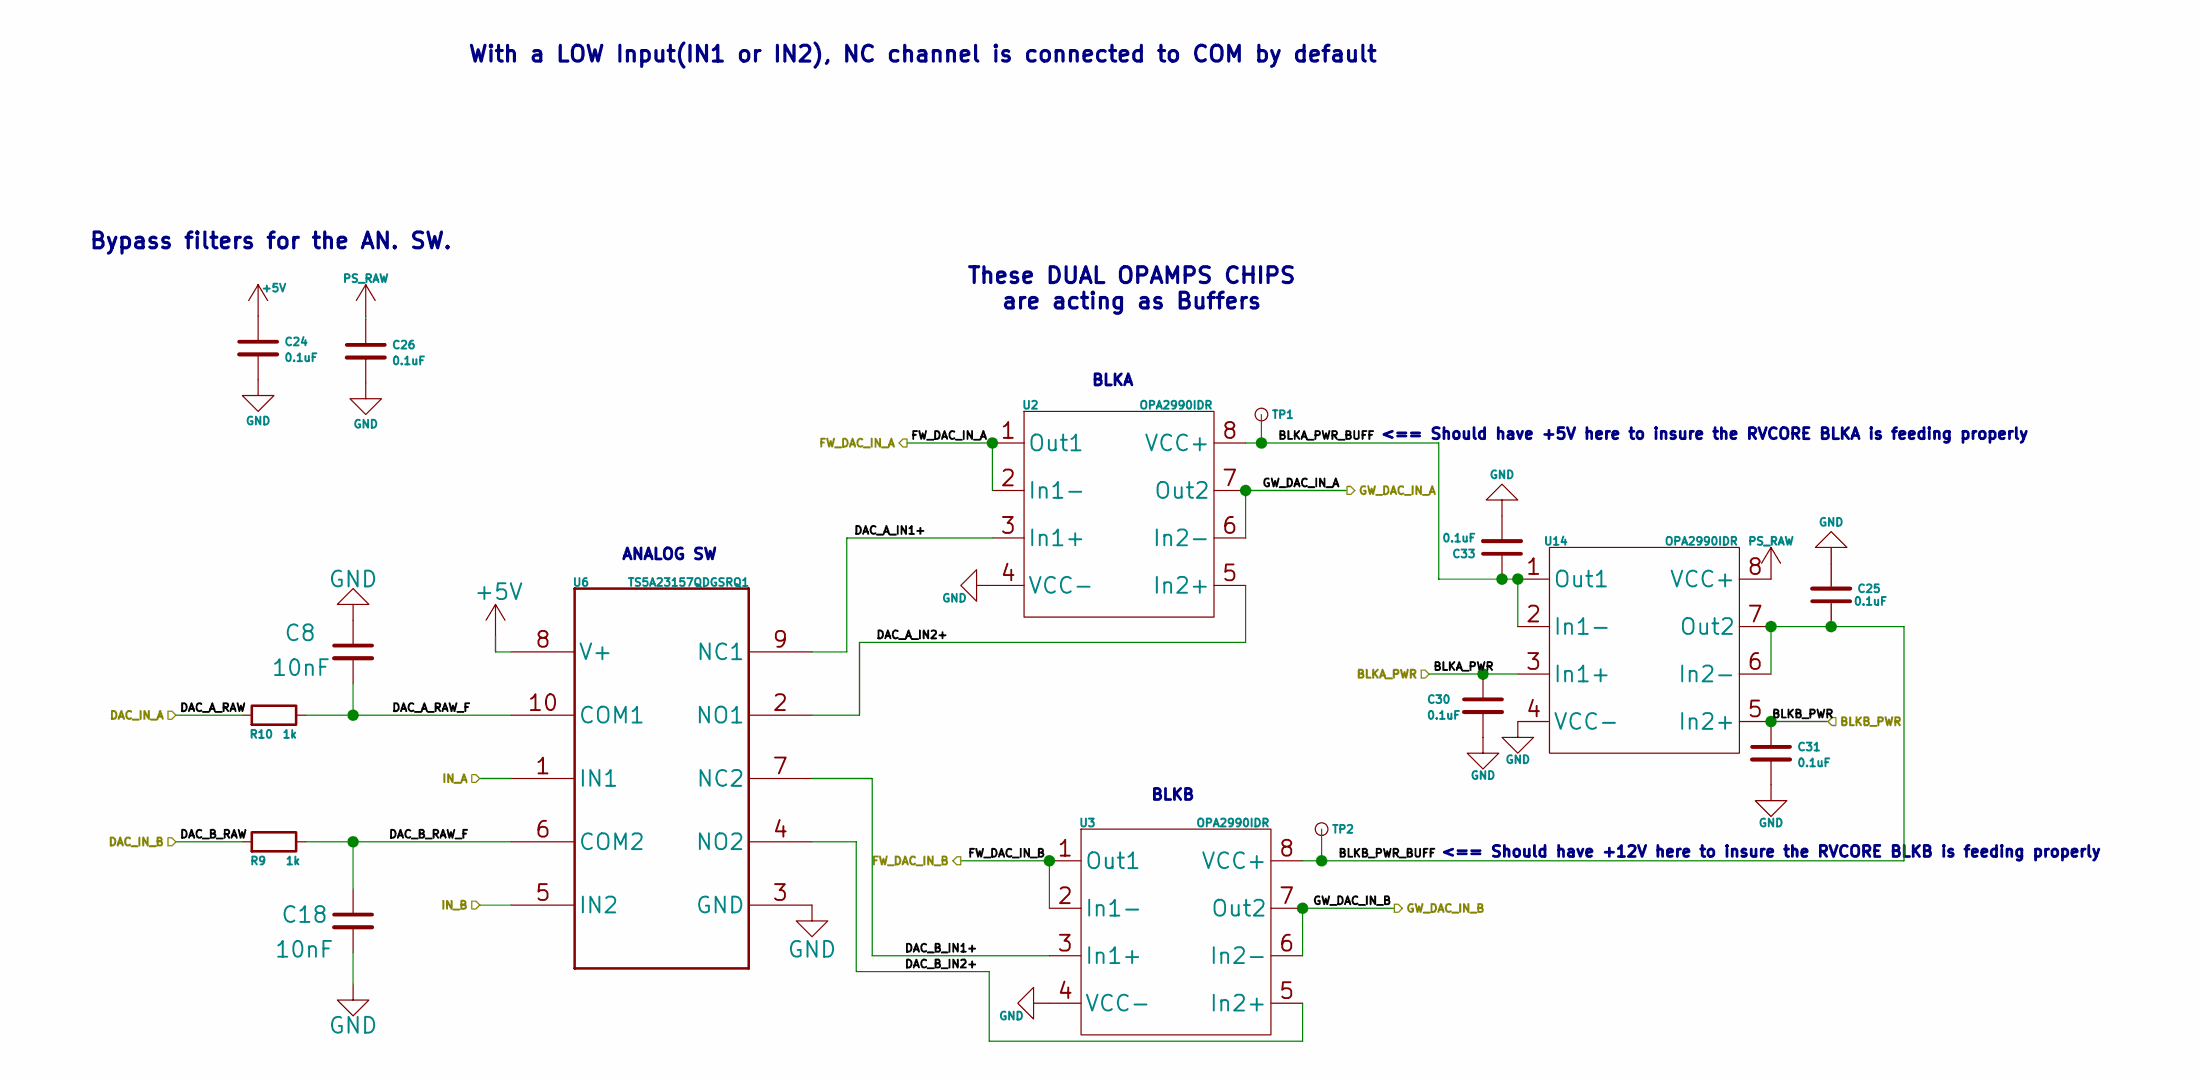
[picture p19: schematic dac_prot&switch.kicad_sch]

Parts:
C8, C18: 10nF; C_0603_1608Metric
C24, C25, C26, C30, C31, C33: 0.1uF; C_0603_1608Metric
R9, R10: 1k; R_0603_1608Metric
TP1: TP1; TestPoint_Pad_D1.5mm
TP2: TP2; TestPoint_Pad_D1.5mm
U2, U3, U14: OPA2990IDR; D8_TEX-M
U6: TS5A23157QDGSRQ1; DGS0010A_N

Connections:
+5V: C24.1, U6.8 (V+); also elsewhere on the board
/DAC_PROT&SWITCH/BLKA_PWR: C30.1, U14.3 (In1+); also elsewhere on the board
/DAC_PROT&SWITCH/BLKA_PWR_BUFF: C33.1, TP1.1, U2.8 (VCC+), U14.1 (Out1), U14.2 (In1-)
/DAC_PROT&SWITCH/BLKB_PWR: C31.1, U14.5 (In2+); also elsewhere on the board
/DAC_PROT&SWITCH/BLKB_PWR_BUFF: C25.1, TP2.1, U3.8 (VCC+), U14.6 (In2-), U14.7 (Out2)
/DAC_PROT&SWITCH/DAC_A_IN1+: U2.3 (In1+), U6.9 (NC1)
/DAC_PROT&SWITCH/DAC_A_IN2+: U2.5 (In2+), U6.2 (NO1)
/DAC_PROT&SWITCH/DAC_A_RAW_F: C8.2, R10.2, U6.10 (COM1)
/DAC_PROT&SWITCH/DAC_B_IN1+: U3.3 (In1+), U6.7 (NC2)
/DAC_PROT&SWITCH/DAC_B_IN2+: U3.5 (In2+), U6.4 (NO2)
/DAC_PROT&SWITCH/DAC_B_RAW_F: C18.1, R9.2, U6.6 (COM2)
/DAC_PROT&SWITCH/FW_DAC_IN_A: U2.1 (Out1), U2.2 (In1-); also elsewhere on the board
/DAC_PROT&SWITCH/GW_DAC_IN_A: U2.6 (In2-), U2.7 (Out2); also elsewhere on the board
DAC_IN_A: R10.1; also elsewhere on the board
DAC_IN_B: R9.1; also elsewhere on the board
FW_DAC_IN_B: U3.1 (Out1), U3.2 (In1-); also elsewhere on the board
GND: C8.1, C18.2, C24.2, C25.2, C26.2, C30.2, C31.2, C33.2, U2.4 (VCC-), U3.4 (VCC-), U6.3 (GND), U14.4 (VCC-); also elsewhere on the board
GW_DAC_IN_B: U3.6 (In2-), U3.7 (Out2); also elsewhere on the board
IN_A: U6.1 (IN1); also elsewhere on the board
IN_B: U6.5 (IN2); also elsewhere on the board
PS_RAW: C26.1, U14.8 (VCC+); also elsewhere on the board

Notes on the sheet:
Bypass filters for the AN. SW.
ANALOG SW
BLKA
<== Should have +12V here to insure the RVCORE BLKB is feeding properly
<== Should have +5V here to insure the RVCORE BLKA is feeding properly
These DUAL OPAMPS CHIPS are acting as Buffers
With a LOW Input(IN1 or IN2), NC channel is connected to COM by default
BLKB

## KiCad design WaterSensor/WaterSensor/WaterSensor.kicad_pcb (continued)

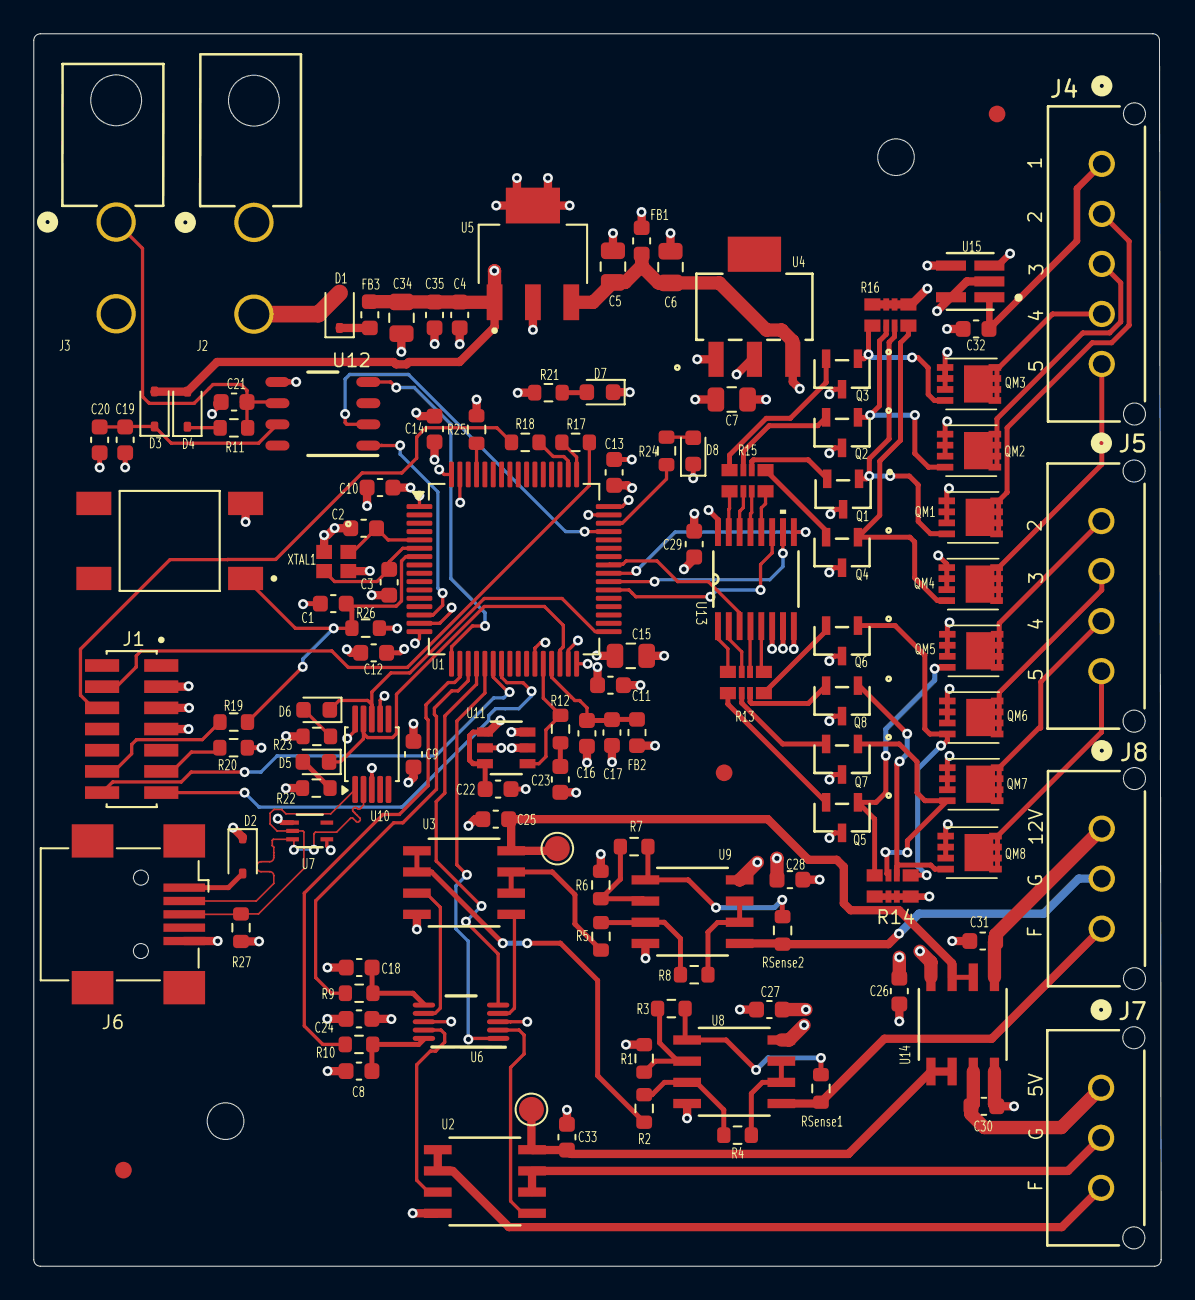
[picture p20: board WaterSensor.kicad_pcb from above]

Board: 4 copper layers, 67.6 x 73.9 mm, 123 parts (0 on the bottom side), 104 nets.

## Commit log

2026-01-07 first commit of water sensor design
    [MCU.kicad_sch, VIConverter.kicad_sch, WaterSensor.kicad_pcb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]
2026-01-10 schematic done
    [MCU.kicad_sch, VIConverter.kicad_sch, WaterSensor.kicad_sch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]
2026-01-12 faltan pines para bloque C
2026-02-17 ready to manufacture
    [BOM.xlsx, MCU.kicad_sch, VIConverter.kicad_sch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]
2026-02-17 Add PCB module description to README
    Added description of PCB module functionality and specifications.
